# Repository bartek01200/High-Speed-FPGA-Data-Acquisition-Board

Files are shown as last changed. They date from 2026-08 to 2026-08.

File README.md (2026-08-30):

# ECP5 FPGA High Speed Data Acquisition System
A custom 4-layer mixed signal data acquisition PCB designed around a Lattice ECP5 FPGA and an analog devices AD9280 8 bit, 32 MSPS ADC.

The system combines analogue signal conditioning, multi rail power regulation, FPGA configuration circuitry and an 8-bit parallel ADC interface with a modular verilog acquisition pipeline for sample capture, FIFO buffering, acquisition control and streamed readout.

## Key Features:
- Lattice ECP5 LFE5U-12F-6BG256C FPGA
- Analog Devices AD9280 8 bit, 32 MSPS ADC
- Custom 4-layer mixed-signal PCB
- OPA836 analogue signal conditioning
- 1.1 V, 2.5 V and 3.3 V power rails
- 8-bit parallel ADC-to-FPGA interface
- FPGA configuration flash and JTAG programming interface
- Verilog ADC capture, FIFO buffering and acquisition control
- FSM-based buffered readout
- HDL simulation using Icarus Verilog and GTKWave
- FPGA synthesis using Yosys
- ECP5 place and route using nextpnr
- 32 MHz FPGA timing target successfully met

## Key metrics include:
The FPGA datapath handles a theoretical raw ADC input rate of 256 Mbit/s(32 MB/s), uses a 16-byte FIFO
,and met a 32MHz timing,using only 58 LUTs and 44 flip flop.

## Front PCB
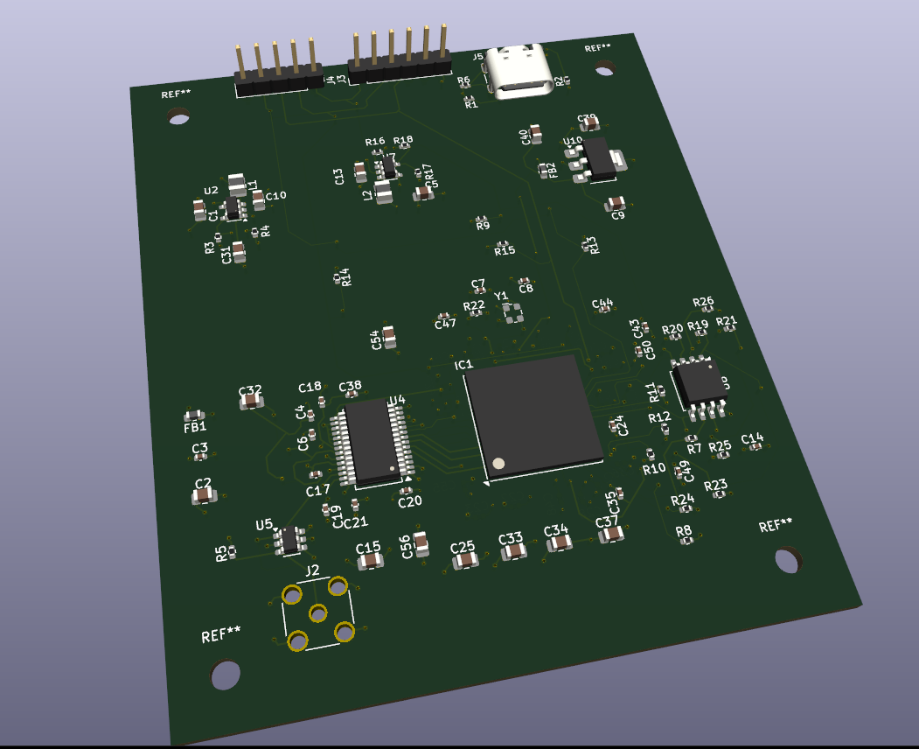
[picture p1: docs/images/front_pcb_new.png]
Front PCB


## Back PCB
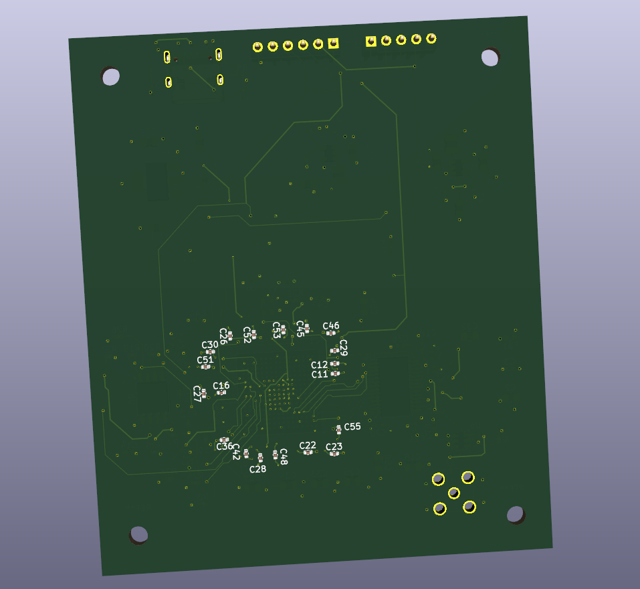
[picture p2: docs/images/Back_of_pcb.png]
Back PCB


## Hardware Build Disclaimer
This project was intended to be physically assembled and tested. However, Mouser cancelled the component order before shipment due to complience issues.I later found that all analog devices needed customer verification which i was not aware of, this included critical parts such as the AD9280 ADC and LT1963 2.5 V regulator.

As a result, the project was completed through PCB design, HDL simulation, synthesis and timing verification rather than physical hardware testing.

AI usage: Used AI for command line guidance and toolchain troubleshooting. All PCB design, HDL implementation, integration, simulation, and project documentation were completed by me.

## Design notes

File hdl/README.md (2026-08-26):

## FPGA HDL

This folder contains the Verilog implementation and simulation files for the FPGA data-acquisition path.
The design targets the Lattice ECP5`LFE5U-12F-6BG256C and implements an acquisition pipeline for the 8-bit parallel output of the AD9280 ADC.

## HDL Architecture
The FPGA datapath is divided into four main modules:

### adc_capture.v
Registers the incoming 8-bit ADC data on the sampling clock edge.
This provides a stable representation of each ADC sample inside the FPGA.

### `fifo.v`
Implements a synchronous FIFO used to buffer ADC samples.
The FIFO separates sample acquisition from readout so that acquired data can be stored before being transferred to the output interface.

It contains:
- sample memory
- write pointer
- read pointer
- occupancy counter
- full and empty status signals

### acquisition_ctrl.v
Controls when sampling begins and ends.

A start input begins an acquisition and the controller counts the required number of samples before disabling capture and asserting done.

### stream_tx.v
Reads samples from the FIFO and presents them through an 8-bit valid/ready streaming interface.
A three-state finite state machine is used:

IDLE → WAIT_FIFO → SEND

The WAIT_FIFO state accounts for the synchronous read latency of the FIFO before asserting tx_valid.

### daq_system.v
Top-level integration of the acquisition system.

The overall logic chain is:
ADC Data → Capture / Acquisition Control → FIFO → Stream Controller → Output

##Simulation
Icarus Verilog was used to simulate the HDL and GTKWave was used to inspect the resulting waveforms.

Individual modules were tested before integrating the complete system.
The final system test used the following sample sequence:
0x10 → 0x20 → 0x30 → 0x40 → 0x50 → 0x60 → 0x70 → 0x80

The same sequence was observed at the streamed output with no missing or reordered samples.

## Debugging and Design Changes

### FIFO Read Latency
The original streaming logic attempted to transmit FIFO data during the same cycle that a read was requested.
Because the FIFO uses synchronous reads, the requested value is not available until the following clock cycle.

The transmitter was therefore redesigned using:
IDLE → WAIT_FIFO → SEND
This ensures that the FIFO output is valid before transmission.

### ADC Pipeline Alignment
During integration, a one-clock offset was observed between the registered ADC sample and the FIFO write operation.

This occurred because non-blocking assignments update registers after the active clock event.

For the final simplified acquisition path, the FIFO write data was aligned directly with the ADC input bus while the registered sample remained available for monitoring and verification.

## 32 MHz Verification
The full acquisition datapath was simulated using a 31.25 ns clock period, corresponding to 32 MHz.
The complete sample sequence remained correct during the 32 MHz simulation.

The RTL was then:
- synthesized using Yosys
- placed and routed using nextpnr-ecp5
- timing analysed against a 32 MHz target
- packaged into an ECP5 bitstream using ecppack

The placed-and-routed design reported:
PASS at 32.00 MHz

with an internal maximum clock frequency of approximately:
233.54 MHz

The 233.54 MHz value represents the timing capability of the analysed internal FPGA paths and is not the sampling rate of the complete mixed-signal system.

## Physical Constraints
The PCB clock is connected to FPGA ball `E7`.
The AD9280 parallel data bus is mapped as follows:

 ADC ECP5 Ball 
- D0 - A2 
- D1 - B3 
- D2 - A3 
- D3 - A4 
- D4 - E4 
- D5 - D4 
- D6 - C4 
- D7 - B4 

Some simulation-oriented top-level interfaces were left physically unconstrained during timing analysis because the PCB was not assembled.

## Tools
- Verilog
- OSS CAD Suite
- Icarus Verilog
- GTKWave
- Yosys
- nextpnr-ecp5
- Project Trellis /ecppack

## Status
Completed:
- ADC capture logic
- FIFO buffering
- acquisition control
- streamed FIFO readout
- module level simulation
- full system simulation
- 32 MHz simulation
- ECP5 synthesis
- place and route
- 32 MHz timing verification
- bitstream generation

Not physically verified due to the board not being assembled.

### End to end simulation:
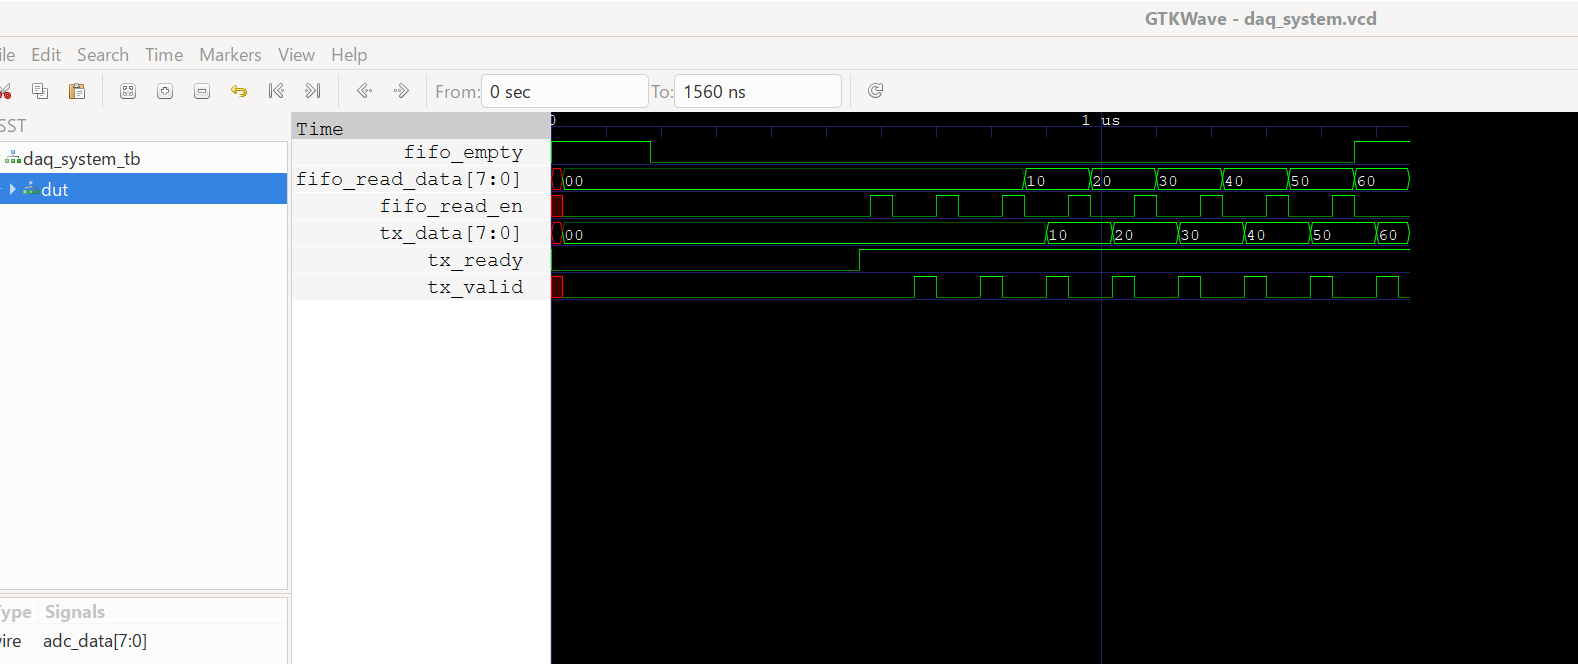
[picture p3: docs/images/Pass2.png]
DAQ system waveform


### FPGA timing verification:
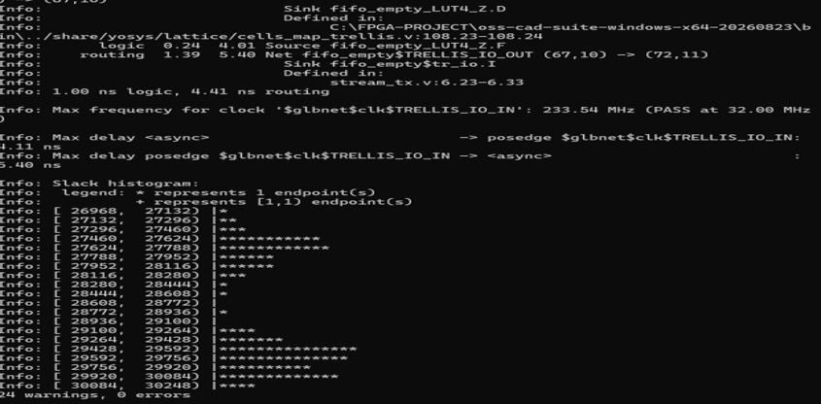
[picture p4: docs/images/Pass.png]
32MHz timing verification


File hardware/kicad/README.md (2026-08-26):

# Hardware Design

This folder contains the hardware design files for the high Speed FPGA Data Acquisition Board.

The board was designed around a Lattice ECP5 FPGA and Analog Devices AD9280 8-bit ADC, with analogue signal conditioning, multi rail power regulation, FPGA configuration circuitry and parallel ADC-to-FPGA routing implemented on a custom 4-layer PCB.

## Main components
- **FPGA:** Lattice  LFE5U-12F-6BG256C
- **ADC:** Analog Devices  AD9280ARSZRL — 8-bit ADC, rated up to 32 MSPS
- **Analogue Amplifier:** OPA836
- **Configuration Flash:** W25Q128JVS
- **System Oscillator:** 25 MHz ECS-2520MV oscillator
- **3.3 V Regulator:** TLV62569
- **1.1 V FPGA Core Regulator:** TLV62569
- **2.5 V Regulator:** LT1963
- **Programming Interface:** JTAG
- **Power Input:** USB-C

## PCB stack up
The board uses a 4-layer stack-up:
A 4-layer was chosen instead of a simpler 2-layer board because the design combines a BGA FPGA, parallel ADC data routing, multiple power rails and sensitive analogue circuitry.

 Layer - Purpose 
 F.Cu  - Components and primary signal routing 
 In1.Cu  -Continuous ground plane 
 In2.Cu  -Power distribution 
 B.Cu -Secondary signal routing 

Using a dedicated ground plane gives high speed signals a short return path, reduces loop area and makes the ADC to FPGA routing easier to read.

A separate internal power layer also makes it easier to distribute the 1.1V, 2.5V, 3.3V, 3.3VA and 5 V rails without filling the signal layers with wide power traces.

A 2-layer board would have made BGA escape routing, power distribution and maintaining good return paths a lot  more difficult.

## Power architecture
The board generates several supply rails from the USB-C 5 V input:

- 5 V — main input supply
- .3 V — FPGA I/O and digital circuitry
- 3.3 VA — filtered analogue supply
- 2.5 V — FPGA auxiliary supply
  - 1.1 V — FPGA core supply

Ferrite bead filtering is used to separate sensitive analogue supply sections from the main digital power network.
Local decoupling capacitors are positioned around the FPGA, ADC and supporting ICs to provide high-frequency current locally and reduce supply noise.

## ADC to FPGA Interface
The AD9280 presents each conversion to the FPGA through an 8-bit parallel digital bus.

 ADC Data - FPGA Ball 

- D0  - A2 
- D1  - B3 
- D2  - A3 
- D3  - A4 
- D4  - E4 
- D5  - D4 
- D6  - C4 
- D7  - B4 

This parallel interface allows the FPGA to capture the complete 8-bit ADC output on each sampling clock.

##Clocking
The board contains a **25 MHz oscillator** connected to FPGA ball E7.

`E7` is the physical BGA connection through which the clock signal enters the FPGA.

The clock provides the timing reference used by the FPGA logic and ADC acquisition system.

- The AD9280 itself is rated for operation up to 32 MSPS. The current PCB uses a 25 MHz onboard oscillator, so operation of the physical board at 32 MSPS would require an appropriate clock-source revision.

##FPGA Configuration

The hardware includes:
- JTAG programming interface
- External SPI configuration flash
- FPGA configuration support circuitry

The JTAG interface allows direct FPGA programming and debugging, while the external flash provides non volatile storage for FPGA configuration data.

## PCB Layout Considerations
The layout was designed with consideration for:
- Continuous signal return paths
- Short ADC-to-FPGA parallel routes
- Local decoupling
- Separation of analogue and digital power distribution
- FPGA BGA escape routing
- Dedicated internal ground plane
- Multi rail FPGA power requirements
- Short switching regulator current loops
  
##Design Status
The schematic and PCB layout have been completed and PCB design rule checks were performed.

The board has not been physically fabricated or electrically validated, therefore hardware performance measurements are outside the scope of the current project.

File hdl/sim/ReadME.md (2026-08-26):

#HDL simulation

The RTL was verified using Icarus Verliog and GTKWave

Verification order:
- adc_capture_tb.v - ADC input capture

- fifo_tb.v - FIFO write/read behaviour

- daq_core_tb.v - integrated ADC capture and buffering

- daq_system_tb.v = complete acquistion and streamed readout

  final system simulation used a 32Mhz clock verified:

  0x10 -> 0x20 -> 0x30 -> 0x40 -> 0x50 -> 0x60 -> 0x70 -> 0x80

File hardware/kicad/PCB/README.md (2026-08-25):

##PCB Design Rules
The PCB was routed as a 4-layer board with the following main design rules:

Parameter - Value 
- General signal trace width - 0.20 mm
- FPGA BGA escape trace width - 0.10 mm
- Standard via size - 0.60 mm 
- Standard via drill - 0.30 mm 
- BGA escape via size - 0.40 mm 
- BGA escape via drill - 0.20 mm 
- FPGA BGA pitch - 0.80 mm 
- Board thickness - 1.6 mm 
- Outer copper thickness - 35 µm

-checked with design rules checker-
## Priority zones

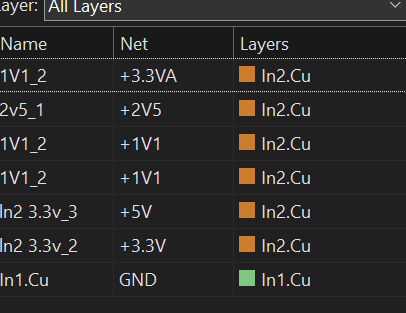
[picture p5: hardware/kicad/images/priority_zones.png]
Power Zone Priorities


Power-zone priority: +3.3VA → +2.5V → +1.1V → +5V → +3.3V. Higher priority zones retain their copper area where zones approach or overlap, helping preserve supply distribution.

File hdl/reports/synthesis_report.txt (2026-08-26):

 /----------------------------------------------------------------------------\
 |  yosys -- Yosys Open SYnthesis Suite                                       |
 |  Copyright (C) 2012 - 2026  Claire Xenia Wolf <claire@yosyshq.com>         |
 |  Distributed under an ISC-like license, type "license" to see terms        |
 \----------------------------------------------------------------------------/
 Yosys 0.68+120 (git sha1 a34d3baae-dirty, Release, GNU /usr/bin/x86_64-w64-mingw32-g++ 15.2.1)

-- Running command `read_verilog adc_capture.v fifo.v acquisition_ctrl.v stream_tx.v daq_system.v; synth_ecp5 -top daq_system -json build/daq_system.json' --

1. Executing Verilog-2005 frontend: adc_capture.v
Parsing Verilog input from `adc_capture.v' to AST representation.
Generating RTLIL representation for module `\adc_capture'.
Successfully finished Verilog frontend.

2. Executing Verilog-2005 frontend: fifo.v
Parsing Verilog input from `fifo.v' to AST representation.
Generating RTLIL representation for module `\fifo'.
Successfully finished Verilog frontend.

3. Executing Verilog-2005 frontend: acquisition_ctrl.v
Parsing Verilog input from `acquisition_ctrl.v' to AST representation.
Generating RTLIL representation for module `\acquisition_ctrl'.
Successfully finished Verilog frontend.

4. Executing Verilog-2005 frontend: stream_tx.v
Parsing Verilog input from `stream_tx.v' to AST representation.
Generating RTLIL representation for module `\stream_tx'.
Successfully finished Verilog frontend.

5. Executing Verilog-2005 frontend: daq_system.v
Parsing Verilog input from `daq_system.v' to AST representation.
Generating RTLIL representation for module `\daq_system'.
Successfully finished Verilog frontend.

6. Executing SYNTH_LATTICE pass.

6.1. Executing Verilog-2005 frontend: C:\FPGA-PROJECT\oss-cad-suite-windows-x64-20260823\bin\../share/yosys/lattice/cells_sim_ecp5.v
Parsing Verilog input from `C:\FPGA-PROJECT\oss-cad-suite-windows-x64-20260823\bin\../share/yosys/lattice/cells_sim_ecp5.v' to AST representation.
Generating RTLIL representation for module `\LUT4'.
Generating RTLIL representation for module `\$__ABC9_LUT5'.
Generating RTLIL representation for module `\$__ABC9_LUT6'.
Generating RTLIL representation for module `\$__ABC9_LUT7'.
Generating RTLIL representation for module `\L6MUX21'.
Generating RTLIL representation for module `\TRELLIS_RAM16X2'.
Generating RTLIL representation for module `\PFUMX'.
Generating RTLIL representation for module `\TRELLIS_DPR16X4'.
Generating RTLIL representation for module `\DPR16X4C'.
Generating RTLIL representation for module `\LUT2'.
Generating RTLIL representation for module `\TRELLIS_FF'.
Generating RTLIL representation for module `\TRELLIS_IO'.
Generating RTLIL representation for module `\INV'.
Generating RTLIL representation for module `\TRELLIS_COMB'.
Generating RTLIL representation for module `\VLO'.
Generating RTLIL representation for module `\VHI'.
Generating RTLIL representation for module `\FD1P3AX'.
Generating RTLIL representation for module `\FD1P3AY'.
Generating RTLIL representation for module `\FD1P3BX'.
Generating RTLIL representation for module `\FD1P3DX'.
Generating RTLIL representation for module `\FD1P3IX'.
Generating RTLIL representation for module `\FD1P3JX'.
Generating RTLIL representation for module `\FD1S3AX'.
Generating RTLIL representation for module `\FD1S3AY'.
Generating RTLIL representation for module `\FD1S3BX'.
Generating RTLIL representation for module `\FD1S3DX'.
Generating RTLIL representation for module `\FD1S3IX'.
Generating RTLIL representation for module `\FD1S3JX'.
Generating RTLIL representation for module `\IFS1P3BX'.
Generating RTLIL representation for module `\IFS1P3DX'.
Generating RTLIL representation for module `\IFS1P3IX'.
Generating RTLIL representation for module `\IFS1P3JX'.
Generating RTLIL representation for module `\OFS1P3BX'.
Generating RTLIL representation for module `\OFS1P3DX'.
Generating RTLIL representation for module `\OFS1P3IX'.
Generating RTLIL representation for module `\OFS1P3JX'.
Generating RTLIL representation for module `\IB'.
Generating RTLIL representation for module `\IBPU'.
Generating RTLIL representation for module `\IBPD'.
Generating RTLIL representation for module `\OB'.
Generating RTLIL representation for module `\OBZ'.
Generating RTLIL representation for module `\OBZPU'.
Generating RTLIL representation for module `\OBZPD'.
Generating RTLIL representation for module `\OBCO'.
Generating RTLIL representation for module `\BB'.
Generating RTLIL representation for module `\BBPU'.
Generating RTLIL representation for module `\BBPD'.
Generating RTLIL representation for module `\ILVDS'.
Generating RTLIL representation for module `\OLVDS'.
Generating RTLIL representation for module `\CCU2C'.
Generating RTLIL representation for module `\DP16KD'.
Replacing existing blackbox module `\FD1P3AX' at C:\FPGA-PROJECT\oss-cad-suite-windows-x64-20260823\bin\../share/yosys/lattice\cells_ff.vh:2.1-2.261.
Generating RTLIL representation for module `\FD1P3AX'.
Replacing existing blackbox module `\FD1P3AY' at C:\FPGA-PROJECT\oss-cad-suite-windows-x64-20260823\bin\../share/yosys/lattice\cells_ff.vh:3.1-3.261.
Generating RTLIL representation for module `\FD1P3AY'.
Replacing existing blackbox module `\FD1P3BX' at C:\FPGA-PROJECT\oss-cad-suite-windows-x64-20260823\bin\../share/yosys/lattice\cells_ff.vh:4.1-4.261.
Generating RTLIL representation for module `\FD1P3BX'.
Replacing existing blackbox module `\FD1P3DX' at C:\FPGA-PROJECT\oss-cad-suite-windows-x64-20260823\bin\../share/yosys/lattice\cells_ff.vh:5.1-5.261.
Generating RTLIL representation for module `\FD1P3DX'.
Replacing existing blackbox module `\FD1P3IX' at C:\FPGA-PROJECT\oss-cad-suite-windows-x64-20260823\bin\../share/yosys/lattice\cells_ff.vh:6.1-6.261.
Generating RTLIL representation for module `\FD1P3IX'.
Replacing existing blackbox module `\FD1P3JX' at C:\FPGA-PROJECT\oss-cad-suite-windows-x64-20260823\bin\../share/yosys/lattice\cells_ff.vh:7.1-7.261.
Generating RTLIL representation for module `\FD1P3JX'.
Replacing existing blackbox module `\FD1S3AX' at C:\FPGA-PROJECT\oss-cad-suite-windows-x64-20260823\bin\../share/yosys/lattice\cells_ff.vh:8.1-8.261.
Generating RTLIL representation for module `\FD1S3AX'.
Replacing existing blackbox module `\FD1S3AY' at C:\FPGA-PROJECT\oss-cad-suite-windows-x64-20260823\bin\../share/yosys/lattice\cells_ff.vh:9.1-9.261.
Generating RTLIL representation for module `\FD1S3AY'.
Replacing existing blackbox module `\FD1S3BX' at C:\FPGA-PROJECT\oss-cad-suite-windows-x64-20260823\bin\../share/yosys/lattice\cells_ff.vh:10.1-10.261.
Generating RTLIL representation for module `\FD1S3BX'.
Replacing existing blackbox module `\FD1S3DX' at C:\FPGA-PROJECT\oss-cad-suite-windows-x64-20260823\bin\../share/yosys/lattice\cells_ff.vh:11.1-11.261.
Generating RTLIL representation for module `\FD1S3DX'.
Replacing existing blackbox module `\FD1S3IX' at C:\FPGA-PROJECT\oss-cad-suite-windows-x64-20260823\bin\../share/yosys/lattice\cells_ff.vh:12.1-12.261.
Generating RTLIL representation for module `\FD1S3IX'.
Replacing existing blackbox module `\FD1S3JX' at C:\FPGA-PROJECT\oss-cad-suite-windows-x64-20260823\bin\../share/yosys/lattice\cells_ff.vh:13.1-13.261.
Generating RTLIL representation for module `\FD1S3JX'.
Replacing existing blackbox module `\IFS1P3BX' at C:\FPGA-PROJECT\oss-cad-suite-windows-x64-20260823\bin\../share/yosys/lattice\cells_ff.vh:26.1-26.301.
Generating RTLIL representation for module `\IFS1P3BX'.
Replacing existing blackbox module `\IFS1P3DX' at C:\FPGA-PROJECT\oss-cad-suite-windows-x64-20260823\bin\../share/yosys/lattice\cells_ff.vh:27.1-27.301.
Generating RTLIL representation for module `\IFS1P3DX'.
Replacing existing blackbox module `\IFS1P3IX' at C:\FPGA-PROJECT\oss-cad-suite-windows-x64-20260823\bin\../share/yosys/lattice\cells_ff.vh:28.1-28.301.
Generating RTLIL representation for module `\IFS1P3IX'.
Replacing existing blackbox module `\IFS1P3JX' at C:\FPGA-PROJECT\oss-cad-suite-windows-x64-20260823\bin\../share/yosys/lattice\cells_ff.vh:29.1-29.301.
Generating RTLIL representation for module `\IFS1P3JX'.
Replacing existing blackbox module `\OFS1P3BX' at C:\FPGA-PROJECT\oss-cad-suite-windows-x64-20260823\bin\../share/yosys/lattice\cells_ff.vh:31.1-31.302.
Generating RTLIL representation for module `\OFS1P3BX'.
Replacing existing blackbox module `\OFS1P3DX' at C:\FPGA-PROJECT\oss-cad-suite-windows-x64-20260823\bin\../share/yosys/lattice\cells_ff.vh:32.1-32.302.
Generating RTLIL representation for module `\OFS1P3DX'.
Replacing existing blackbox module `\OFS1P3IX' at C:\FPGA-PROJECT\oss-cad-suite-windows-x64-20260823\bin\../share/yosys/lattice\cells_ff.vh:33.1-33.302.
Generating RTLIL representation for module `\OFS1P3IX'.
Replacing existing blackbox module `\OFS1P3JX' at C:\FPGA-PROJECT\oss-cad-suite-windows-x64-20260823\bin\../share/yosys/lattice\cells_ff.vh:34.1-34.302.
Generating RTLIL representation for module `\OFS1P3JX'.
Replacing existing blackbox module `\IB' at C:\FPGA-PROJECT\oss-cad-suite-windows-x64-20260823\bin\../share/yosys/lattice\cells_io.vh:2.1-2.157.
Generating RTLIL representation for module `\IB'.
Replacing existing blackbox module `\IBPU' at C:\FPGA-PROJECT\oss-cad-suite-windows-x64-20260823\bin\../share/yosys/lattice\cells_io.vh:3.1-3.157.
Generating RTLIL representation for module `\IBPU'.
Replacing existing blackbox module `\IBPD' at C:\FPGA-PROJECT\oss-cad-suite-windows-x64-20260823\bin\../share/yosys/lattice\cells_io.vh:4.1-4.157.
Generating RTLIL representation for module `\IBPD'.
Replacing existing blackbox module `\OB' at C:\FPGA-PROJECT\oss-cad-suite-windows-x64-20260823\bin\../share/yosys/lattice\cells_io.vh:5.1-5.157.
Generating RTLIL representation for module `\OB'.
Replacing existing blackbox module `\OBZ' at C:\FPGA-PROJECT\oss-cad-suite-windows-x64-20260823\bin\../share/yosys/lattice\cells_io.vh:6.1-6.164.
Generating RTLIL representation for module `\OBZ'.
Replacing existing blackbox module `\OBZPU' at C:\FPGA-PROJECT\oss-cad-suite-windows-x64-20260823\bin\../share/yosys/lattice\cells_io.vh:7.1-7.164.
Generating RTLIL representation for module `\OBZPU'.
Replacing existing blackbox module `\OBZPD' at C:\FPGA-PROJECT\oss-cad-suite-windows-x64-20260823\bin\../share/yosys/lattice\cells_io.vh:8.1-8.164.
Generating RTLIL representation for module `\OBZPD'.
Replacing existing blackbox module `\OBCO' at C:\FPGA-PROJECT\oss-cad-suite-windows-x64-20260823\bin\../share/yosys/lattice\cells_io.vh:9.1-9.90.
Generating RTLIL representation for module `\OBCO'.
Replacing existing blackbox module `\BB' at C:\FPGA-PROJECT\oss-cad-suite-windows-x64-20260823\bin\../share/yosys/lattice\cells_io.vh:10.1-10.179.
Generating RTLIL representation for module `\BB'.
Replacing existing blackbox module `\BBPU' at C:\FPGA-PROJECT\oss-cad-suite-windows-x64-20260823\bin\../share/yosys/lattice\cells_io.vh:11.1-11.179.
Generating RTLIL representation for module `\BBPU'.
Replacing existing blackbox module `\BBPD' at C:\FPGA-PROJECT\oss-cad-suite-windows-x64-20260823\bin\../share/yosys/lattice\cells_io.vh:12.1-12.179.
Generating RTLIL representation for module `\BBPD'.
Replacing existing blackbox module `\ILVDS' at C:\FPGA-PROJECT\oss-cad-suite-windows-x64-20260823\bin\../share/yosys/lattice\cells_io.vh:13.1-13.139.
Generating RTLIL representation for module `\ILVDS'.
Replacing existing blackbox module `\OLVDS' at C:\FPGA-PROJECT\oss-cad-suite-windows-x64-20260823\bin\../share/yosys/lattice\cells_io.vh:14.1-14.146.
Generating RTLIL representation for module `\OLVDS'.
Successfully finished Verilog frontend.

6.2. Executing Verilog-2005 frontend: C:\FPGA-PROJECT\oss-cad-suite-windows-x64-20260823\bin\../share/yosys/lattice/cells_bb_ecp5.v
Parsing Verilog input from `C:\FPGA-PROJECT\oss-cad-suite-windows-x64-20260823\bin\../share/yosys/lattice/cells_bb_ecp5.v' to AST representation.
Generating RTLIL representation for module `\GSR'.
Generating RTLIL representation for module `\PUR'.
Generating RTLIL representation for module `\SGSR'.
Generating RTLIL representation for module `\PDPW16KD'.
Generating RTLIL representation for module `\MULT18X18D'.
Generating RTLIL representation for module `\ALU54B'.
Generating RTLIL representation for module `\CLKDIVF'.
Generating RTLIL representation for module `\PCSCLKDIV'.
Generating RTLIL representation for module `\DCSC'.
Generating RTLIL representation for module `\DCCA'.
Generating RTLIL representation for module `\ECLKSYNCB'.
Generating RTLIL representation for module `\ECLKBRIDGECS'.
Generating RTLIL representation for module `\DELAYF'.
Generating RTLIL representation for module `\DELAYG'.
Generating RTLIL representation for module `\USRMCLK'.
Generating RTLIL representation for module `\DQSBUFM'.
Generating RTLIL representation for module `\DDRDLLA'.
Generating RTLIL representation for module `\DLLDELD'.
Generating RTLIL representation for module `\IDDRX1F'.
Generating RTLIL representation for module `\IDDRX2F'.
Generating RTLIL representation for module `\IDDR71B'.
Generating RTLIL representation for module `\IDDRX2DQA'.
Generating RTLIL representation for module `\ODDRX1F'.
Generating RTLIL representation for module `\ODDRX2F'.
Generating RTLIL representation for module `\ODDR71B'.
Generating RTLIL representation for module `\OSHX2A'.
Generating RTLIL representation for module `\TSHX2DQA'.
Generating RTLIL representation for module `\TSHX2DQSA'.
Generating RTLIL representation for module `\ODDRX2DQA'.
Generating RTLIL representation for module `\ODDRX2DQSB'.
Generating RTLIL representation for module `\EHXPLLL'.
Generating RTLIL representation for module `\DTR'.
Generating RTLIL representation for module `\OSCG'.
Generating RTLIL representation for module `\EXTREFB'.
Generating RTLIL representation for module `\JTAGG'.
Generating RTLIL representation for module `\DCUA'.
Successfully finished Verilog frontend.

6.3. Executing HIERARCHY pass (managing design hierarchy).

6.3.1. Analyzing design hierarchy..
Top module:  \daq_system
Used module:     \stream_tx
Used module:     \fifo
Used module:     \acquisition_ctrl
Used module:     \adc_capture
Parameter \DATA_WIDTH = 8
Parameter \DEPTH = 16
Parameter \ADDR_WIDTH = 4

6.3.2. Executing AST frontend in derive mode using pre-parsed AST for module `\fifo'.
Parameter \DATA_WIDTH = 8
Parameter \DEPTH = 16
Parameter \ADDR_WIDTH = 4
Generating RTLIL representation for module `$paramod$6a1231bad6349c99ef10c6a6a58dbbf16b7d2bdb\fifo'.
Parameter \SAMPLE_COUNT = 8

6.3.3. Executing AST frontend in derive mode using pre-parsed AST for module `\acquisition_ctrl'.
Parameter \SAMPLE_COUNT = 8
Generating RTLIL representation for module `$paramod\acquisition_ctrl\SAMPLE_COUNT=s32'00000000000000000000000000001000'.

6.3.4. Analyzing design hierarchy..
Top module:  \daq_system
Used module:     \stream_tx
Used module:     $paramod$6a1231bad6349c99ef10c6a6a58dbbf16b7d2bdb\fifo
Used module:     $paramod\acquisition_ctrl\SAMPLE_COUNT=s32'00000000000000000000000000001000
Used module:     \adc_capture

6.3.5. Analyzing design hierarchy..
Top module:  \daq_system
Used module:     \stream_tx
Used module:     $paramod$6a1231bad6349c99ef10c6a6a58dbbf16b7d2bdb\fifo
Used module:     $paramod\acquisition_ctrl\SAMPLE_COUNT=s32'00000000000000000000000000001000
Used module:     \adc_capture
Removing unused module `\acquisition_ctrl'.
Removing unused module `\fifo'.
Removed 2 unused modules.

6.4. Executing PROC pass (convert processes to netlists).

6.4.1. Executing PROC_CLEAN pass (remove empty switches from decision trees).
Cleaned up 0 empty switches.

6.4.2. Executing PROC_RMDEAD pass (remove dead branches from decision trees).
Marked 2 switch rules as full_case in process $proc$stream_tx.v:20$38 in module stream_tx.
Marked 2 switch rules as full_case in process $proc$acquisition_ctrl.v:12$297 in module $paramod\acquisition_ctrl\SAMPLE_COUNT=s32'00000000000000000000000000001000.
Marked 3 switch rules as full_case in process $proc$fifo.v:27$271 in module $paramod$6a1231bad6349c99ef10c6a6a58dbbf16b7d2bdb\fifo.
Removed a total of 0 dead cases.

6.4.3. Executing PROC_PRUNE pass (remove redundant assignments in processes).
Removed 3 redundant assignments.
Promoted 8 assignments to connections.

6.4.4. Executing PROC_INIT pass (extract init attributes).
Found init rule in `$paramod$6a1231bad6349c99ef10c6a6a58dbbf16b7d2bdb\fifo.$proc$fifo.v:23$296'.
  Set init value: \count = 5'00000
Found init rule in `$paramod$6a1231bad6349c99ef10c6a6a58dbbf16b7d2bdb\fifo.$proc$fifo.v:21$295'.
  Set init value: \read_ptr = 4'0000
Found init rule in `$paramod$6a1231bad6349c99ef10c6a6a58dbbf16b7d2bdb\fifo.$proc$fifo.v:20$294'.
  Set init value: \write_ptr = 4'0000

6.4.5. Executing PROC_ARST pass (detect async resets in processes).

6.4.6. Executing PROC_ROM pass (convert switches to ROMs).
Converted 0 switches.
<suppressed ~11 debug messages>

6.4.7. Executing PROC_MUX pass (convert decision trees to multiplexers).
Creating decoders for process `\stream_tx.$proc$stream_tx.v:20$38'.
     1/4: $0\tx_valid[0:0]
     2/4: $0\fifo_read_en[0:0]
     3/4: $0\state[1:0]
     4/4: $0\tx_data[7:0]
Creating decoders for process `$paramod\acquisition_ctrl\SAMPLE_COUNT=s32'00000000000000000000000000001000.$proc$acquisition_ctrl.v:12$297'.
     1/3: $0\sample_counter[7:0]
     2/3: $0\done[0:0]
     3/3: $0\capture_en[0:0]
Creating decoders for process `$paramod$6a1231bad6349c99ef10c6a6a58dbbf16b7d2bdb\fifo.$proc$fifo.v:23$296'.
Creating decoders for process `$paramod$6a1231bad6349c99ef10c6a6a58dbbf16b7d2bdb\fifo.$proc$fifo.v:21$295'.
Creating decoders for process `$paramod$6a1231bad6349c99ef10c6a6a58dbbf16b7d2bdb\fifo.$proc$fifo.v:20$294'.
Creating decoders for process `$paramod$6a1231bad6349c99ef10c6a6a58dbbf16b7d2bdb\fifo.$proc$fifo.v:27$271'.
     1/10: $2$memwr$\memory$fifo.v:36$268_EN[7:0]$282
     2/10: $2$memwr$\memory$fifo.v:36$268_DATA[7:0]$281
     3/10: $2$memwr$\memory$fifo.v:36$268_ADDR[3:0]$280
     4/10: $0\count[4:0]
     5/10: $1$memwr$\memory$fifo.v:36$268_EN[7:0]$277
     6/10: $1$memwr$\memory$fifo.v:36$268_DATA[7:0]$276
     7/10: $1$memwr$\memory$fifo.v:36$268_ADDR[3:0]$275
     8/10: $0\read_ptr[3:0]
     9/10: $0\write_ptr[3:0]
    10/10: $0\read_data[7:0]
Creating decoders for process `\adc_capture.$proc$adc_capture.v:9$1'.

6.4.8. Executing PROC_DLATCH pass (convert process syncs to latches).

6.4.9. Executing PROC_DFF pass (convert process syncs to FFs).
Creating register for signal `\stream_tx.\fifo_read_en' using process `\stream_tx.$proc$stream_tx.v:20$38'.
  created $dff cell `$procdff$414' with positive edge clock.
Creating register for signal `\stream_tx.\tx_data' using process `\stream_tx.$proc$stream_tx.v:20$38'.
  created $dff cell `$procdff$415' with positive edge clock.
Creating register for signal `\stream_tx.\tx_valid' using process `\stream_tx.$proc$stream_tx.v:20$38'.
  created $dff cell `$procdff$416' with positive edge clock.
Creating register for signal `\stream_tx.\state' using process `\stream_tx.$proc$stream_tx.v:20$38'.
  created $dff cell `$procdff$417' with positive edge clock.
Creating register for signal `$paramod\acquisition_ctrl\SAMPLE_COUNT=s32'00000000000000000000000000001000.\capture_en' using process `$paramod\acquisition_ctrl\SAMPLE_COUNT=s32'00000000000000000000000000001000.$proc$acquisition_ctrl.v:12$297'.
  created $dff cell `$procdff$418' with positive edge clock.
Creating register for signal `$paramod\acquisition_ctrl\SAMPLE_COUNT=s32'00000000000000000000000000001000.\done' using process `$paramod\acquisition_ctrl\SAMPLE_COUNT=s32'00000000000000000000000000001000.$proc$acquisition_ctrl.v:12$297'.
  created $dff cell `$procdff$419' with positive edge clock.
Creating register for signal `$paramod\acquisition_ctrl\SAMPLE_COUNT=s32'00000000000000000000000000001000.\sample_counter' using process `$paramod\acquisition_ctrl\SAMPLE_COUNT=s32'00000000000000000000000000001000.$proc$acquisition_ctrl.v:12$297'.
  created $dff cell `$procdff$420' with positive edge clock.
Creating register for signal `$paramod$6a1231bad6349c99ef10c6a6a58dbbf16b7d2bdb\fifo.\read_data' using process `$paramod$6a1231bad6349c99ef10c6a6a58dbbf16b7d2bdb\fifo.$proc$fifo.v:27$271'.
  created $dff cell `$procdff$421' with positive edge clock.
Creating register for signal `$paramod$6a1231bad6349c99ef10c6a6a58dbbf16b7d2bdb\fifo.\write_ptr' using process `$paramod$6a1231bad6349c99ef10c6a6a58dbbf16b7d2bdb\fifo.$proc$fifo.v:27$271'.
  created $dff cell `$procdff$422' with positive edge clock.
Creating register for signal `$paramod$6a1231bad6349c99ef10c6a6a58dbbf16b7d2bdb\fifo.\read_ptr' using process `$paramod$6a1231bad6349c99ef10c6a6a58dbbf16b7d2bdb\fifo.$proc$fifo.v:27$271'.
  created $dff cell `$procdff$423' with positive edge clock.
Creating register for signal `$paramod$6a1231bad6349c99ef10c6a6a58dbbf16b7d2bdb\fifo.\count' using process `$paramod$6a1231bad6349c99ef10c6a6a58dbbf16b7d2bdb\fifo.$proc$fifo.v:27$271'.
  created $dff cell `$procdff$424' with positive edge clock.
Creating register for signal `$paramod$6a1231bad6349c99ef10c6a6a58dbbf16b7d2bdb\fifo.$memwr$\memory$fifo.v:36$268_ADDR' using process `$paramod$6a1231bad6349c99ef10c6a6a58dbbf16b7d2bdb\fifo.$proc$fifo.v:27$271'.
  created $dff cell `$procdff$425' with positive edge clock.
Creating register for signal `$paramod$6a1231bad6349c99ef10c6a6a58dbbf16b7d2bdb\fifo.$memwr$\memory$fifo.v:36$268_DATA' using process `$paramod$6a1231bad6349c99ef10c6a6a58dbbf16b7d2bdb\fifo.$proc$fifo.v:27$271'.
  created $dff cell `$procdff$426' with positive edge clock.
Creating register for signal `$paramod$6a1231bad6349c99ef10c6a6a58dbbf16b7d2bdb\fifo.$memwr$\memory$fifo.v:36$268_EN' using process `$paramod$6a1231bad6349c99ef10c6a6a58dbbf16b7d2bdb\fifo.$proc$fifo.v:27$271'.
  created $dff cell `$procdff$427' with positive edge clock.
Creating register for signal `\adc_capture.\sample' using process `\adc_capture.$proc$adc_capture.v:9$1'.
  created $dff cell `$procdff$428' with positive edge clock.
Creating register for signal `\adc_capture.\sample_valid' using process `\adc_capture.$proc$adc_capture.v:9$1'.
  created $dff cell `$procdff$429' with positive edge clock.

6.4.10. Executing PROC_MEMWR pass (convert process memory writes to cells).

6.4.11. Executing PROC_CLEAN pass (remove empty switches from decision trees).
Found and cleaned up 3 empty switches in `\stream_tx.$proc$stream_tx.v:20$38'.
Removing empty process `stream_tx.$proc$stream_tx.v:20$38'.
Found and cleaned up 4 empty switches in `$paramod\acquisition_ctrl\SAMPLE_COUNT=s32'00000000000000000000000000001000.$proc$acquisition_ctrl.v:12$297'.
Removing empty process `$paramod\acquisition_ctrl\SAMPLE_COUNT=s32'00000000000000000000000000001000.$proc$acquisition_ctrl.v:12$297'.
Removing empty process `$paramod$6a1231bad6349c99ef10c6a6a58dbbf16b7d2bdb\fifo.$proc$fifo.v:23$296'.
Removing empty process `$paramod$6a1231bad6349c99ef10c6a6a58dbbf16b7d2bdb\fifo.$proc$fifo.v:21$295'.
Removing empty process `$paramod$6a1231bad6349c99ef10c6a6a58dbbf16b7d2bdb\fifo.$proc$fifo.v:20$294'.
Found and cleaned up 4 empty switches in `$paramod$6a1231bad6349c99ef10c6a6a58dbbf16b7d2bdb\fifo.$proc$fifo.v:27$271'.
Removing empty process `$paramod$6a1231bad6349c99ef10c6a6a58dbbf16b7d2bdb\fifo.$proc$fifo.v:27$271'.
Removing empty process `adc_capture.$proc$adc_capture.v:9$1'.
Cleaned up 11 empty switches.

6.4.12. Executing OPT_EXPR pass (perform const folding).
Optimizing module daq_system.
Optimizing module stream_tx.
<suppressed ~2 debug messages>
Optimizing module $paramod\acquisition_ctrl\SAMPLE_COUNT=s32'00000000000000000000000000001000.
Optimizing module $paramod$6a1231bad6349c99ef10c6a6a58dbbf16b7d2bdb\fifo.
<suppressed ~1 debug messages>
Optimizing module adc_capture.

6.5. Executing CHECK pass (checking for obvious problems).
Checking module daq_system...
Checking module stream_tx...
Checking module $paramod\acquisition_ctrl\SAMPLE_COUNT=s32'00000000000000000000000000001000...
Checking module $paramod$6a1231bad6349c99ef10c6a6a58dbbf16b7d2bdb\fifo...
Checking module adc_capture...
Found and reported 0 problems.

6.6. Executing FLATTEN pass (flatten design).
Deleting now unused module stream_tx.
Deleting now unused module $paramod\acquisition_ctrl\SAMPLE_COUNT=s32'00000000000000000000000000001000.
Deleting now unused module $paramod$6a1231bad6349c99ef10c6a6a58dbbf16b7d2bdb\fifo.
Deleting now unused module adc_capture.
<suppressed ~4 debug messages>

6.7. Executing TRIBUF pass.

6.8. Executing DEMINOUT pass (demote inout ports to input or output).

6.9. Executing OPT_EXPR pass (perform const folding).
Optimizing module daq_system.

6.10. Executing OPT_CLEAN pass (remove unused cells and wires).
Finding unused cells or wires in module \daq_system..
Removed 5 unused cells and 68 unused wires.
<suppressed ~10 debug messages>

6.11. Executing CHECK pass (checking for obvious problems).
Checking module daq_system...
Found and reported 0 problems.

6.12. Executing OPT pass (performing simple optimizations).

6.12.1. Executing OPT_EXPR pass (perform const folding).
Optimizing module daq_system.

6.12.2. Executing OPT_MERGE pass (detect identical cells).
Finding identical cells in module `\daq_system'.
Computing hashes of 86 cells of `\daq_system'.
Finding duplicate cells in `\daq_system'.
Computing hashes of 80 cells of `\daq_system'.
Finding duplicate cells in `\daq_system'.
Computing hashes of 78 cells of `\daq_system'.
Finding duplicate cells in `\daq_system'.
<suppressed ~24 debug messages>
Removed a total of 8 cells.

6.12.3. Executing OPT_MUXTREE pass (detect dead branches in mux trees).
Running muxtree optimizer on module \daq_system..
  Creating internal representation of mux trees.
  Evaluating internal representation of mux trees.
  Analyzing evaluation results.
    dead port 1/2 on $mux $flatten\fifo_inst.$procmux$368.
    dead port 1/2 on $mux $flatten\fifo_inst.$procmux$374.
    dead port 1/2 on $mux $flatten\fifo_inst.$procmux$380.
Removed 3 multiplexer ports.
<suppressed ~58 debug messages>

6.12.4. Executing OPT_REDUCE pass (consolidate $*mux and $reduce_* inputs).
  Optimizing cells in module \daq_system.
    Consolidated identical input bits for $mux cell $flatten\fifo_inst.$procmux$365:
      Old ports: A=8'00000000, B=8'11111111, Y=$flatten\fifo_inst.$procmux$365_Y
      New ports: A=1'0, B=1'1, Y=$flatten\fifo_inst.$procmux$365_Y [0]
      New connections: $flatten\fifo_inst.$procmux$365_Y [7:1] = { $flatten\fifo_inst.$procmux$365_Y [0] $flatten\fifo_inst.$procmux$365_Y [0] $flatten\fifo_inst.$procmux$365_Y [0] $flatten\fifo_inst.$procmux$365_Y [0] $flatten\fifo_inst.$procmux$365_Y [0] $flatten\fifo_inst.$procmux$365_Y [0] $flatten\fifo_inst.$procmux$365_Y [0] }
  Optimizing cells in module \daq_system.
    Consolidated identical input bits for $mux cell $flatten\fifo_inst.$procmux$390:
      Old ports: A=$flatten\fifo_inst.$2$memwr$\memory$fifo.v:36$268_EN[7:0]$282, B=8'00000000, Y=$flatten\fifo_inst.$0$memwr$\memory$fifo.v:36$268_EN[7:0]$274
      New ports: A=$flatten\fifo_inst.$procmux$365_Y [0], B=1'0, Y=$flatten\fifo_inst.$0$memwr$\memory$fifo.v:36$268_EN[7:0]$274 [0]
      New connections: $flatten\fifo_inst.$0$memwr$\memory$fifo.v:36$268_EN[7:0]$274 [7:1] = { $flatten\fifo_inst.$0$memwr$\memory$fifo.v:36$268_EN[7:0]$274 [0] $flatten\fifo_inst.$0$memwr$\memory$fifo.v:36$268_EN[7:0]$274 [0] $flatten\fifo_inst.$0$memwr$\memory$fifo.v:36$268_EN[7:0]$274 [0] $flatten\fifo_inst.$0$memwr$\memory$fifo.v:36$268_EN[7:0]$274 [0] $flatten\fifo_inst.$0$memwr$\memory$fifo.v:36$268_EN[7:0]$274 [0] $flatten\fifo_inst.$0$memwr$\memory$fifo.v:36$268_EN[7:0]$274 [0] $flatten\fifo_inst.$0$memwr$\memory$fifo.v:36$268_EN[7:0]$274 [0] }
  Optimizing cells in module \daq_system.
Performed a total of 2 changes.

6.12.5. Executing OPT_MERGE pass (detect identical cells).
Finding identical cells in module `\daq_system'.
Computing hashes of 75 cells of `\daq_system'.
Finding duplicate cells in `\daq_system'.
Removed a total of 0 cells.

6.12.6. Executing OPT_DFF pass (perform DFF optimizations).

6.12.7. Executing OPT_CLEAN pass (remove unused cells and wires).
Finding unused cells or wires in module \daq_system..
Removed 0 unused cells and 11 unused wires.
<suppressed ~1 debug messages>

6.12.8. Executing OPT_EXPR pass (perform const folding).
Optimizing module daq_system.

6.12.9. Rerunning OPT passes. (Maybe there is more to do..)

6.12.10. Executing OPT_MUXTREE pass (detect dead branches in mux trees).
Running muxtree optimizer on module \daq_system..
  Creating internal representation of mux trees.
  Evaluating internal representation of mux trees.
  Analyzing evaluation results.
Removed 0 multiplexer ports.
<suppressed ~55 debug messages>

6.12.11. Executing OPT_REDUCE pass (consolidate $*mux and $reduce_* inputs).
  Optimizing cells in module \daq_system.
Performed a total of 0 changes.

6.12.12. Executing OPT_MERGE pass (detect identical cells).
Finding identical cells in module `\daq_system'.
Computing hashes of 75 cells of `\daq_system'.
Finding duplicate cells in `\daq_system'.
Removed a total of 0 cells.

6.12.13. Executing OPT_DFF pass (perform DFF optimizations).

6.12.14. Executing OPT_CLEAN pass (remove unused cells and wires).
Finding unused cells or wires in module \daq_system..

6.12.15. Executing OPT_EXPR pass (perform const folding).
Optimizing module daq_system.

6.12.16. Finished fast OPT passes. (There is nothing left to do.)

6.13. Executing FSM pass (extract and optimize FSM).

6.13.1. Executing FSM_DETECT pass (finding FSMs in design).
Found FSM state register daq_system.stream_inst.state.

6.13.2. Executing FSM_EXTRACT pass (extracting FSM from design).
Extracting FSM `\stream_inst.state' from module `\daq_system'.
  found $dff cell for state register: $flatten\stream_inst.$procdff$417
  root of input selection tree: $flatten\stream_inst.$0\state[1:0]
  found reset state: 2'00 (guessed from mux tree)
  found ctrl input: \reset
  found ctrl input: $flatten\stream_inst.$procmux$323_CMP
  found ctrl input: $flatten\stream_inst.$procmux$316_CMP
  found state code: 2'00
  found state code: 2'10
  found ctrl input: $flatten\stream_inst.$logic_and$stream_tx.v:34$40_Y
  found state code: 2'01
  found ctrl output: $flatten\stream_inst.$procmux$306_CMP
  found ctrl output: $flatten\stream_inst.$procmux$323_CMP
  found ctrl output: $flatten\stream_inst.$procmux$316_CMP
  ctrl inputs: { $flatten\stream_inst.$logic_and$stream_tx.v:34$40_Y \reset }
  ctrl outputs: { $flatten\stream_inst.$0\state[1:0] $flatten\stream_inst.$procmux$306_CMP $flatten\stream_inst.$procmux$316_CMP $flatten\stream_inst.$procmux$323_CMP }
  transition:       2'00 2'00 ->       2'00 5'00010
  transition:       2'00 2'10 ->       2'01 5'01010
  transition:       2'00 2'-1 ->       2'00 5'00010
  transition:       2'10 2'-0 ->       2'00 5'00100
  transition:       2'10 2'-1 ->       2'00 5'00100
  transition:       2'01 2'-0 ->       2'10 5'10001
  transition:       2'01 2'-1 ->       2'00 5'00001

6.13.3. Executing FSM_OPT pass (simple optimizations of FSMs).
Optimizing FSM `$fsm$\stream_inst.state$435' from module `\daq_system'.
  Merging pattern 2'-0 and 2'-1 from group (1 0 5'00100).
  Merging pattern 2'-1 and 2'-0 from group (1 0 5'00100).

6.13.4. Executing OPT_CLEAN pass (remove unused cells and wires).
Finding unused cells or wires in module \daq_system..
Removed 7 unused cells and 7 unused wires.
<suppressed ~8 debug messages>

6.13.5. Executing FSM_OPT pass (simple optimizations of FSMs).
Optimizing FSM `$fsm$\stream_inst.state$435' from module `\daq_system'.
  Removing unused output signal $flatten\stream_inst.$procmux$323_CMP.
  Removing unused output signal $flatten\stream_inst.$0\state[1:0] [0].
  Removing unused output signal $flatten\stream_inst.$0\state[1:0] [1].

6.13.6. Executing FSM_RECODE pass (re-assigning FSM state encoding).
Recoding FSM `$fsm$\stream_inst.state$435' from module `\daq_system' using `auto' encoding:
  mapping auto encoding to `one-hot` for this FSM.
  00 -> --1
  10 -> -1-
  01 -> 1--

6.13.7. Executing FSM_INFO pass (dumping all available information on FSM cells).

FSM `$fsm$\stream_inst.state$435' from module `daq_system':
-------------------------------------

  Information on FSM $fsm$\stream_inst.state$435 (\stream_inst.state):

  Number of input signals:    2
  Number of output signals:   2
  Number of state bits:       3

  Input signals:
    0: \reset
    1: $flatten\stream_inst.$logic_and$stream_tx.v:34$40_Y

  Output signals:
    0: $flatten\stream_inst.$procmux$316_CMP
    1: $flatten\stream_inst.$procmux$306_CMP

  State encoding:
    0:      3'--1  <RESET STATE>
    1:      3'-1-
    2:      3'1--

  Transition Table (state_in, ctrl_in, state_out, ctrl_out):
      0:     0 2'00   ->     0 2'01
      1:     0 2'-1   ->     0 2'01
      2:     0 2'10   ->     2 2'01
      3:     1 2'--   ->     0 2'10
      4:     2 2'-1   ->     0 2'00
      5:     2 2'-0   ->     1 2'00

-------------------------------------

6.13.8. Executing FSM_MAP pass (mapping FSMs to basic logic).
Mapping FSM `$fsm$\stream_inst.state$435' from module `\daq_system'.

6.14. Executing OPT pass (performing simple optimizations).

6.14.1. Executing OPT_EXPR pass (perform const folding).
Optimizing module daq_system.
<suppressed ~3 debug messages>

6.14.2. Executing OPT_MERGE pass (detect identical cells).
Finding identical cells in module `\daq_system'.
Computing hashes of 76 cells of `\daq_system'.
Finding duplicate cells in `\daq_system'.
Removed a total of 0 cells.

6.14.3. Executing OPT_MUXTREE pass (detect dead branches in mux trees).
Running muxtree optimizer on module \daq_system..
  Creating internal representation of mux trees.
  Evaluating internal representation of mux trees.
  Analyzing evaluation results.
Removed 0 multiplexer ports.
<suppressed ~51 debug messages>

6.14.4. Executing OPT_REDUCE pass (consolidate $*mux and $reduce_* inputs).
  Optimizing cells in module \daq_system.
Performed a total of 0 changes.

6.14.5. Executing OPT_MERGE pass (detect identical cells).
Finding identical cells in module `\daq_system'.
Computing hashes of 76 cells of `\daq_system'.
Finding duplicate cells in `\daq_system'.
Removed a total of 0 cells.

6.14.6. Executing OPT_DFF pass (perform DFF optimizations).
Adding SRST signal on $flatten\stream_inst.$procdff$416 ($dff) from module daq_system (D = $flatten\stream_inst.$procmux$305_Y, Q = \stream_inst.tx_valid, rval = 1'0).
Adding SRST signal on $flatten\control_inst.$procdff$420 ($dff) from module daq_system (D = $flatten\control_inst.$procmux$341_Y, Q = \control_inst.sample_counter, rval = 8'00000000).
Adding SRST signal on $flatten\control_inst.$procdff$419 ($dff) from module daq_system (D = $flatten\control_inst.$procmux$349_Y, Q = \control_inst.done, rval = 1'0).
Adding EN signal on $auto$ff.cc:337:slice$461 ($sdff) from module daq_system (D = 1'1, Q = \control_inst.done).
Adding SRST signal on $flatten\control_inst.$procdff$418 ($dff) from module daq_system (D = $flatten\control_inst.$procmux$359_Y, Q = \control_inst.capture_en, rval = 1'0).
Adding SRST signal on $flatten\fifo_inst.$procdff$424 ($dff) from module daq_system (D = $flatten\fifo_inst.$procmux$383_Y, Q = \fifo_inst.count, rval = 5'00000).
Adding EN signal on $auto$ff.cc:337:slice$466 ($sdff) from module daq_system (D = $flatten\fifo_inst.$procmux$383_Y, Q = \fifo_inst.count).
Adding SRST signal on $flatten\fifo_inst.$procdff$423 ($dff) from module daq_system (D = $flatten\fifo_inst.$procmux$398_Y, Q = \fifo_inst.read_ptr, rval = 4'0000).
Adding EN signal on $auto$ff.cc:337:slice$470 ($sdff) from module daq_system (D = $flatten\fifo_inst.$add$fifo.v:42$287_Y, Q = \fifo_inst.read_ptr).
Adding SRST signal on $flatten\fifo_inst.$procdff$422 ($dff) from module daq_system (D = $flatten\fifo_inst.$procmux$404_Y, Q = \fifo_inst.write_ptr, rval = 4'0000).
Adding EN signal on $auto$ff.cc:337:slice$472 ($sdff) from module daq_system (D = $flatten\fifo_inst.$add$fifo.v:37$283_Y, Q = \fifo_inst.write_ptr).
Adding SRST signal on $flatten\fifo_inst.$procdff$421 ($dff) from module daq_system (D = $flatten\fifo_inst.$procmux$409_Y, Q = \fifo_inst.read_data, rval = 8'00000000).
Adding EN signal on $auto$ff.cc:337:slice$474 ($sdff) from module daq_system (D = $flatten\fifo_inst.$memrd$\memory$fifo.v:41$286_DATA, Q = \fifo_inst.read_data).
Adding SRST signal on $flatten\stream_inst.$procdff$414 ($dff) from module daq_system (D = $flatten\stream_inst.$procmux$313_Y, Q = \stream_inst.fifo_read_en, rval = 1'0).
Adding SRST signal on $flatten\stream_inst.$procdff$415 ($dff) from module daq_system (D = $flatten\stream_inst.$procmux$331_Y, Q = \stream_inst.tx_data, rval = 8'00000000).
Adding EN signal on $auto$ff.cc:337:slice$481 ($sdff) from module daq_system (D = \fifo_inst.read_data, Q = \stream_inst.tx_data).

6.14.7. Executing OPT_CLEAN pass (remove unused cells and wires).
Finding unused cells or wires in module \daq_system..
Removed 17 unused cells and 24 unused wires.
<suppressed ~18 debug messages>

6.14.8. Executing OPT_EXPR pass (perform const folding).
Optimizing module daq_system.
<suppressed ~1 debug messages>

6.14.9. Rerunning OPT passes. (Maybe there is more to do..)

6.14.10. Executing OPT_MUXTREE pass (detect dead branches in mux trees).
Running muxtree optimizer on module \daq_system..
  Creating internal representation of mux trees.
  Evaluating internal representation of mux trees.
  Analyzing evaluation results.
Removed 0 multiplexer ports.
<suppressed ~29 debug messages>

6.14.11. Executing OPT_REDUCE pass (consolidate $*mux and $reduce_* inputs).
  Optimizing cells in module \daq_system.
Performed a total of 0 changes.

6.14.12. Executing OPT_MERGE pass (detect identical cells).
Finding identical cells in module `\daq_system'.
Computing hashes of 63 cells of `\daq_system'.
Finding duplicate cells in `\daq_system'.
Removed a total of 0 cells.

6.14.13. Executing OPT_DFF pass (perform DFF optimizations).

6.14.14. Executing OPT_CLEAN pass (remove unused cells and wires).
Finding unused cells or wires in module \daq_system..

6.14.15. Executing OPT_EXPR pass (perform const folding).
Optimizing module daq_system.

6.14.16. Finished fast OPT passes. (There is nothing left to do.)

6.15. Executing WREDUCE pass (reducing word size of cells).
Removed top 5 bits (of 8) from port B of cell daq_system.$flatten\control_inst.$eq$acquisition_ctrl.v:24$302 ($eq).
Removed top 1 bits (of 2) from port B of cell daq_system.$flatten\fifo_inst.$procmux$384_CMP0 ($eq).

6.16. Executing PEEPOPT pass (run peephole optimizers).

6.17. Executing OPT_CLEAN pass (remove unused cells and wires).
Finding unused cells or wires in module \daq_system..

6.18. Executing SHARE pass (SAT-based resource sharing).

6.19. Executing TECHMAP pass (map to technology primitives).

6.19.1. Executing Verilog-2005 frontend: C:\FPGA-PROJECT\oss-cad-suite-windows-x64-20260823\bin\../share/yosys/cmp2lut.v
Parsing Verilog input from `C:\FPGA-PROJECT\oss-cad-suite-windows-x64-20260823\bin\../share/yosys/cmp2lut.v' to AST representation.
Generating RTLIL representation for module `\_90_lut_cmp_'.
Successfully finished Verilog frontend.

6.19.2. Continuing TECHMAP pass.
No more expansions possible.
<suppressed ~6 debug messages>

6.20. Executing OPT_EXPR pass (perform const folding).
Optimizing module daq_system.

6.21. Executing OPT_CLEAN pass (remove unused cells and wires).
Finding unused cells or wires in module \daq_system..

6.22. Executing TECHMAP pass (map to technology primitives).

6.22.1. Executing Verilog-2005 frontend: C:\FPGA-PROJECT\oss-cad-suite-windows-x64-20260823\bin\../share/yosys/mul2dsp.v
Parsing Verilog input from `C:\FPGA-PROJECT\oss-cad-suite-windows-x64-20260823\bin\../share/yosys/mul2dsp.v' to AST representation.
Generating RTLIL representation for module `\_80_mul'.
Generating RTLIL representation for module `\_90_soft_mul'.
Successfully finished Verilog frontend.

6.22.2. Continuing TECHMAP pass.
No more expansions possible.
<suppressed ~4 debug messages>

6.23. Executing TECHMAP pass (map to technology primitives).

6.23.1. Executing Verilog-2005 frontend: C:\FPGA-PROJECT\oss-cad-suite-windows-x64-20260823\bin\../share/yosys/lattice/dsp_map_18x18.v
Parsing Verilog input from `C:\FPGA-PROJECT\oss-cad-suite-windows-x64-20260823\bin\../share/yosys/lattice/dsp_map_18x18.v' to AST representation.
Generating RTLIL representation for module `$__MUL18X18'.
Successfully finished Verilog frontend.

6.23.2. Continuing TECHMAP pass.
No more expansions possible.
<suppressed ~3 debug messages>

6.24. Executing ALUMACC pass (create $alu and $macc cells).
Extracting $alu and $macc cells in module daq_system:
  creating $macc model for $flatten\fifo_inst.$add$fifo.v:42$287 ($add).
  creating $macc model for $flatten\fifo_inst.$add$fifo.v:50$292 ($add).
  creating $macc model for $flatten\fifo_inst.$sub$fifo.v:51$293 ($sub).
  creating $macc model for $flatten\fifo_inst.$add$fifo.v:37$283 ($add).
  creating $macc model for $flatten\control_inst.$add$acquisition_ctrl.v:29$303 ($add).
  creating $alu model for $macc $flatten\control_inst.$add$acquisition_ctrl.v:29$303.
  creating $alu model for $macc $flatten\fifo_inst.$add$fifo.v:37$283.
  creating $alu model for $macc $flatten\fifo_inst.$sub$fifo.v:51$293.
  creating $alu model for $macc $flatten\fifo_inst.$add$fifo.v:50$292.
  creating $alu model for $macc $flatten\fifo_inst.$add$fifo.v:42$287.
  creating $alu cell for $flatten\fifo_inst.$add$fifo.v:42$287: $auto$alumacc.cc:548:replace_alu$484
  creating $alu cell for $flatten\fifo_inst.$add$fifo.v:50$292: $auto$alumacc.cc:548:replace_alu$487
  creating $alu cell for $flatten\fifo_inst.$sub$fifo.v:51$293: $auto$alumacc.cc:548:replace_alu$490
  creating $alu cell for $flatten\fifo_inst.$add$fifo.v:37$283: $auto$alumacc.cc:548:replace_alu$493
  creating $alu cell for $flatten\control_inst.$add$acquisition_ctrl.v:29$303: $auto$alumacc.cc:548:replace_alu$496
  created 5 $alu and 0 $macc cells.

6.25. Executing OPT pass (performing simple optimizations).

6.25.1. Executing OPT_EXPR pass (perform const folding).
Optimizing module daq_system.

6.25.2. Executing OPT_MERGE pass (detect identical cells).
Finding identical cells in module `\daq_system'.
Computing hashes of 63 cells of `\daq_system'.
Finding duplicate cells in `\daq_system'.
Removed a total of 0 cells.

6.25.3. Executing OPT_MUXTREE pass (detect dead branches in mux trees).
Running muxtree optimizer on module \daq_system..
  Creating internal representation of mux trees.
  Evaluating internal representation of mux trees.
  Analyzing evaluation results.
Removed 0 multiplexer ports.
<suppressed ~29 debug messages>

6.25.4. Executing OPT_REDUCE pass (consolidate $*mux and $reduce_* inputs).
  Optimizing cells in module \daq_system.
Performed a total of 0 changes.

6.25.5. Executing OPT_MERGE pass (detect identical cells).
Finding identical cells in module `\daq_system'.
Computing hashes of 63 cells of `\daq_system'.
Finding duplicate cells in `\daq_system'.
Removed a total of 0 cells.

6.25.6. Executing OPT_DFF pass (perform DFF optimizations).

6.25.7. Executing OPT_CLEAN pass (remove unused cells and wires).
Finding unused cells or wires in module \daq_system..

6.25.8. Executing OPT_EXPR pass (perform const folding).
Optimizing module daq_system.

6.25.9. Finished fast OPT passes. (There is nothing left to do.)

6.26. Executing MEMORY pass.

6.26.1. Executing OPT_MEM pass (optimize memories).
Performed a total of 0 transformations.

6.26.2. Executing OPT_MEM_PRIORITY pass (removing unnecessary memory write priority relations).
Performed a total of 0 transformations.

6.26.3. Executing OPT_MEM_FEEDBACK pass (finding memory read-to-write feedback paths).
  Analyzing daq_system.fifo_inst.memory write port 0.

6.26.4. Executing MEMORY_BMUX2ROM pass (converting muxes to ROMs).

6.26.5. Executing MEMORY_DFF pass (merging $dff cells to $memrd).
Checking read port `\fifo_inst.memory'[0] in module `\daq_system': merging output FF to cell.
    Write port 0: non-transparent.

6.26.6. Executing OPT_CLEAN pass (remove unused cells and wires).
Finding unused cells or wires in module \daq_system..
Removed 1 unused cells and 9 unused wires.
<suppressed ~2 debug messages>

6.26.7. Executing MEMORY_SHARE pass (consolidating $memrd/$memwr cells).

6.26.8. Executing OPT_MEM_WIDEN pass (optimize memories where all ports are wide).
Performed a total of 0 transformations.

6.26.9. Executing OPT_CLEAN pass (remove unused cells and wires).
Finding unused cells or wires in module \daq_system..

6.26.10. Executing MEMORY_COLLECT pass (generating $mem cells).

6.27. Executing OPT_CLEAN pass (remove unused cells and wires).
Finding unused cells or wires in module \daq_system..

6.28. Executing MEMORY_LIBMAP pass (mapping memories to cells).
mapping memory daq_system.fifo_inst.memory via $__TRELLIS_DPR16X4_
Extracted data FF from read port 0 of daq_system.fifo_inst.memory: $\fifo_inst.memory$rdreg[0]
<suppressed ~491 debug messages>

6.29. Executing TECHMAP pass (map to technology primitives).

6.29.1. Executing Verilog-2005 frontend: C:\FPGA-PROJECT\oss-cad-suite-windows-x64-20260823\bin\../share/yosys/lattice/lutrams_map_trellis.v
Parsing Verilog input from `C:\FPGA-PROJECT\oss-cad-suite-windows-x64-20260823\bin\../share/yosys/lattice/lutrams_map_trellis.v' to AST representation.
Generating RTLIL representation for module `$__TRELLIS_DPR16X4_'.
Successfully finished Verilog frontend.

6.29.2. Executing Verilog-2005 frontend: C:\FPGA-PROJECT\oss-cad-suite-windows-x64-20260823\bin\../share/yosys/lattice/brams_map_16kd.v
Parsing Verilog input from `C:\FPGA-PROJECT\oss-cad-suite-windows-x64-20260823\bin\../share/yosys/lattice/brams_map_16kd.v' to AST representation.
Generating RTLIL representation for module `$__DP16KD_'.
Generating RTLIL representation for module `$__PDPW16KD_'.
Successfully finished Verilog frontend.

6.29.3. Continuing TECHMAP pass.
Using template $paramod$04778961cc1285a5efea28f98f28381eb2862208$__TRELLIS_DPR16X4_ for cells of type $__TRELLIS_DPR16X4_.
No more expansions possible.
<suppressed ~20 debug messages>

6.30. Executing OPT pass (performing simple optimizations).

6.30.1. Executing OPT_EXPR pass (perform const folding).
Optimizing module daq_system.
<suppressed ~8 debug messages>

6.30.2. Executing OPT_MERGE pass (detect identical cells).
Finding identical cells in module `\daq_system'.
Computing hashes of 56 cells of `\daq_system'.
Finding duplicate cells in `\daq_system'.
Removed a total of 0 cells.

6.30.3. Executing OPT_DFF pass (perform DFF optimizations).

6.30.4. Executing OPT_CLEAN pass (remove unused cells and wires).
Finding unused cells or wires in module \daq_system..
Removed 0 unused cells and 21 unused wires.
<suppressed ~1 debug messages>

6.30.5. Finished fast OPT passes.

6.31. Executing MEMORY_MAP pass (converting memories to logic and flip-flops).

6.32. Executing OPT pass (performing simple optimizations).

6.32.1. Executing OPT_EXPR pass (perform const folding).
Optimizing module daq_system.

6.32.2. Executing OPT_MERGE pass (detect identical cells).
Finding identical cells in module `\daq_system'.
Computing hashes of 56 cells of `\daq_system'.
Finding duplicate cells in `\daq_system'.
Removed a total of 0 cells.

6.32.3. Executing OPT_MUXTREE pass (detect dead branches in mux trees).
Running muxtree optimizer on module \daq_system..
  Creating internal representation of mux trees.
  Evaluating internal representation of mux trees.
  Analyzing evaluation results.
Removed 0 multiplexer ports.
<suppressed ~18 debug messages>

6.32.4. Executing OPT_REDUCE pass (consolidate $*mux and $reduce_* inputs).
  Optimizing cells in module \daq_system.
Performed a total of 0 changes.

6.32.5. Executing OPT_MERGE pass (detect identical cells).
Finding identical cells in module `\daq_system'.
Computing hashes of 56 cells of `\daq_system'.
Finding duplicate cells in `\daq_system'.
Removed a total of 0 cells.

6.32.6. Executing OPT_DFF pass (perform DFF optimizations).

6.32.7. Executing OPT_CLEAN pass (remove unused cells and wires).
Finding unused cells or wires in module \daq_system..

6.32.8. Executing OPT_EXPR pass (perform const folding).
Optimizing module daq_system.

6.32.9. Finished fast OPT passes. (There is nothing left to do.)

6.33. Executing TECHMAP pass (map to technology primitives).

6.33.1. Executing Verilog-2005 frontend: C:\FPGA-PROJECT\oss-cad-suite-windows-x64-20260823\bin\../share/yosys/techmap.v
Parsing Verilog input from `C:\FPGA-PROJECT\oss-cad-suite-windows-x64-20260823\bin\../share/yosys/techmap.v' to AST representation.
Generating RTLIL representation for module `\_90_simplemap_bool_ops'.
Generating RTLIL representation for module `\_90_simplemap_reduce_ops'.
Generating RTLIL representation for module `\_90_simplemap_logic_ops'.
Generating RTLIL representation for module `\_90_simplemap_compare_ops'.
Generating RTLIL representation for module `\_90_simplemap_various'.
Generating RTLIL representation for module `\_90_simplemap_registers'.
Generating RTLIL representation for module `\_90_shift_ops_shr_shl_sshl_sshr'.
Generating RTLIL representation for module `\_90_shift_shiftx'.
Generating RTLIL representation for module `\_90_fa'.
Generating RTLIL representation for module `\_90_lcu_brent_kung'.
Generating RTLIL representation for module `\_90_alu'.
Generating RTLIL representation for module `\_90_macc'.
Generating RTLIL representation for module `\_90_alumacc'.
Generating RTLIL representation for module `$__div_mod_u'.
Generating RTLIL representation for module `$__div_mod_trunc'.
Generating RTLIL representation for module `\_90_div'.
Generating RTLIL representation for module `\_90_mod'.
Generating RTLIL representation for module `$__div_mod_floor'.
Generating RTLIL representation for module `\_90_divfloor'.
Generating RTLIL representation for module `\_90_modfloor'.
Generating RTLIL representation for module `\_90_pow'.
Generating RTLIL representation for module `\_90_demux'.
Generating RTLIL representation for module `\_90_lut'.
Generating RTLIL representation for module `$connect'.
Generating RTLIL representation for module `$input_port'.
Successfully finished Verilog frontend.

6.33.2. Executing Verilog-2005 frontend: C:\FPGA-PROJECT\oss-cad-suite-windows-x64-20260823\bin\../share/yosys/lattice/arith_map_ccu2c.v
Parsing Verilog input from `C:\FPGA-PROJECT\oss-cad-suite-windows-x64-20260823\bin\../share/yosys/lattice/arith_map_ccu2c.v' to AST representation.
Generating RTLIL representation for module `\_80_ccu2c_alu'.
Successfully finished Verilog frontend.

6.33.3. Continuing TECHMAP pass.
Using template $paramod$c3cd1564c35d873179656addd6052d7ea8b6d991\_80_ccu2c_alu for cells of type $alu.
Using template $paramod$32a7b7b86c07519b7537abc18e96f0331f97914d\_90_alu for cells of type $alu.
Using template $paramod$dc04b7d98e503a7bab16fce2df70e6e2c5ca34d6\_80_ccu2c_alu for cells of type $alu.
Using template $paramod$672a140277c71df8314410f22acc08d55222c3c7\_80_ccu2c_alu for cells of type $alu.
Using extmapper simplemap for cells of type $sdffe.
Using extmapper simplemap for cells of type $reduce_or.
Using extmapper simplemap for cells of type $not.
Using extmapper simplemap for cells of type $sdff.
Using extmapper simplemap for cells of type $reduce_bool.
Using extmapper simplemap for cells of type $reduce_and.
Using extmapper simplemap for cells of type $and.
Using extmapper simplemap for cells of type $eq.
Using extmapper simplemap for cells of type $logic_not.
Using extmapper simplemap for cells of type $dff.
Using extmapper simplemap for cells of type $logic_and.
Using extmapper simplemap for cells of type $mux.
Using extmapper simplemap for cells of type $logic_or.
Using extmapper simplemap for cells of type $xor.
Using extmapper simplemap for cells of type $pos.
Using template $paramod\_90_fa\WIDTH=32'00000000000000000000000000000100 for cells of type $fa.
Using template $paramod\_90_lcu_brent_kung\WIDTH=32'00000000000000000000000000000100 for cells of type $lcu.
Using extmapper simplemap for cells of type $or.
No more expansions possible.
<suppressed ~446 debug messages>

6.34. Executing OPT pass (performing simple optimizations).

6.34.1. Executing OPT_EXPR pass (perform const folding).
Optimizing module daq_system.
<suppressed ~181 debug messages>

6.34.2. Executing OPT_MERGE pass (detect identical cells).
Finding identical cells in module `\daq_system'.
Computing hashes of 194 cells of `\daq_system'.
Finding duplicate cells in `\daq_system'.
Computing hashes of 180 cells of `\daq_system'.
Finding duplicate cells in `\daq_system'.
Computing hashes of 179 cells of `\daq_system'.
Finding duplicate cells in `\daq_system'.
<suppressed ~45 debug messages>
Removed a total of 15 cells.

6.34.3. Executing OPT_DFF pass (perform DFF optimizations).

6.34.4. Executing OPT_CLEAN pass (remove unused cells and wires).
Finding unused cells or wires in module \daq_system..
Removed 26 unused cells and 217 unused wires.
<suppressed ~27 debug messages>

6.34.5. Finished fast OPT passes.

6.35. Executing OPT_CLEAN pass (remove unused cells and wires).
Finding unused cells or wires in module \daq_system..

6.36. Executing DFFLEGALIZE pass (convert FFs and LATCHes to types supported by the target).

6.37. Executing OPT_MERGE pass (detect identical cells).
Finding identical cells in module `\daq_system'.
Computing hashes of 153 cells of `\daq_system'.
Finding duplicate cells in `\daq_system'.
Removed a total of 0 cells.

6.38. Executing TECHMAP pass (map to technology primitives).

6.38.1. Executing Verilog-2005 frontend: C:\FPGA-PROJECT\oss-cad-suite-windows-x64-20260823\bin\../share/yosys/lattice/cells_map_trellis.v
Parsing Verilog input from `C:\FPGA-PROJECT\oss-cad-suite-windows-x64-20260823\bin\../share/yosys/lattice/cells_map_trellis.v' to AST representation.
Generating RTLIL representation for module `$_DFF_N_'.
Generating RTLIL representation for module `$_DFF_P_'.
Generating RTLIL representation for module `$_DFFE_NN_'.
Generating RTLIL representation for module `$_DFFE_PN_'.
Generating RTLIL representation for module `$_DFFE_NP_'.
Generating RTLIL representation for module `$_DFFE_PP_'.
Generating RTLIL representation for module `$_DFF_NP0_'.
Generating RTLIL representation for module `$_DFF_NP1_'.
Generating RTLIL representation for module `$_DFF_PP0_'.
Generating RTLIL representation for module `$_DFF_PP1_'.
Generating RTLIL representation for module `$_SDFF_NP0_'.
Generating RTLIL representation for module `$_SDFF_NP1_'.
Generating RTLIL representation for module `$_SDFF_PP0_'.
Generating RTLIL representation for module `$_SDFF_PP1_'.
Generating RTLIL representation for module `$_DFFE_NP0P_'.
Generating RTLIL representation for module `$_DFFE_NP1P_'.
Generating RTLIL representation for module `$_DFFE_PP0P_'.
Generating RTLIL representation for module `$_DFFE_PP1P_'.
Generating RTLIL representation for module `$_DFFE_NP0N_'.
Generating RTLIL representation for module `$_DFFE_NP1N_'.
Generating RTLIL representation for module `$_DFFE_PP0N_'.
Generating RTLIL representation for module `$_DFFE_PP1N_'.
Generating RTLIL representation for module `$_SDFFE_NP0P_'.
Generating RTLIL representation for module `$_SDFFE_NP1P_'.
Generating RTLIL representation for module `$_SDFFE_PP0P_'.
Generating RTLIL representation for module `$_SDFFE_PP1P_'.
Generating RTLIL representation for module `$_SDFFE_NP0N_'.
Generating RTLIL representation for module `$_SDFFE_NP1N_'.
Generating RTLIL representation for module `$_SDFFE_PP0N_'.
Generating RTLIL representation for module `$_SDFFE_PP1N_'.
Generating RTLIL representation for module `$_ALDFF_NP_'.
Generating RTLIL representation for module `$_ALDFF_PP_'.
Generating RTLIL representation for module `$_ALDFFE_NPN_'.
Generating RTLIL representation for module `$_ALDFFE_NPP_'.
Generating RTLIL representation for module `$_ALDFFE_PPN_'.
Generating RTLIL representation for module `$_ALDFFE_PPP_'.
Generating RTLIL representation for module `\FD1P3AX'.
Generating RTLIL representation for module `\FD1P3AY'.
Generating RTLIL representation for module `\FD1P3BX'.
Generating RTLIL representation for module `\FD1P3DX'.
Generating RTLIL representation for module `\FD1P3IX'.
Generating RTLIL representation for module `\FD1P3JX'.
Generating RTLIL representation for module `\FD1S3AX'.
Generating RTLIL representation for module `\FD1S3AY'.
Generating RTLIL representation for module `\FD1S3BX'.
Generating RTLIL representation for module `\FD1S3DX'.
Generating RTLIL representation for module `\FD1S3IX'.
Generating RTLIL representation for module `\FD1S3JX'.
Generating RTLIL representation for module `\IFS1P3BX'.
Generating RTLIL representation for module `\IFS1P3DX'.
Generating RTLIL representation for module `\IFS1P3IX'.
Generating RTLIL representation for module `\IFS1P3JX'.
Generating RTLIL representation for module `\OFS1P3BX'.
Generating RTLIL representation for module `\OFS1P3DX'.
Generating RTLIL representation for module `\OFS1P3IX'.
Generating RTLIL representation for module `\OFS1P3JX'.
Generating RTLIL representation for module `\IB'.
Generating RTLIL representation for module `\IBPU'.
Generating RTLIL representation for module `\IBPD'.
Generating RTLIL representation for module `\OB'.
Generating RTLIL representation for module `\OBZ'.
Generating RTLIL representation for module `\OBZPU'.
Generating RTLIL representation for module `\OBZPD'.
Generating RTLIL representation for module `\OBCO'.
Generating RTLIL representation for module `\BB'.
Generating RTLIL representation for module `\BBPU'.
Generating RTLIL representation for module `\BBPD'.
Generating RTLIL representation for module `\ILVDS'.
Generating RTLIL representation for module `\OLVDS'.
Successfully finished Verilog frontend.

6.38.2. Continuing TECHMAP pass.
Using template $_SDFFE_PP0P_ for cells of type $_SDFFE_PP0P_.
Using template $paramod$_DFF_P_\_TECHMAP_WIREINIT_Q_=1'x for cells of type $_DFF_P_.
Using template $_SDFF_PP0_ for cells of type $_SDFF_PP0_.
No more expansions possible.
<suppressed ~126 debug messages>

6.39. Executing OPT_EXPR pass (perform const folding).
Optimizing module daq_system.

6.40. Executing SIMPLEMAP pass (map simple cells to gate primitives).

6.41. Executing LATTICE_GSR pass (implement FF init values).
Handling GSR in daq_system.

6.42. Executing ATTRMVCP pass (move or copy attributes).

6.43. Executing OPT_CLEAN pass (remove unused cells and wires).
Finding unused cells or wires in module \daq_system..
Removed 0 unused cells and 247 unused wires.
<suppressed ~1 debug messages>

6.44. Executing CHECK pass (checking for obvious problems).
Checking module daq_system...
Found and reported 0 problems.

6.45. Executing TECHMAP pass (map to technology primitives).

6.45.1. Executing Verilog-2005 frontend: C:\FPGA-PROJECT\oss-cad-suite-windows-x64-20260823\bin\../share/yosys/lattice/latches_map.v
Parsing Verilog input from `C:\FPGA-PROJECT\oss-cad-suite-windows-x64-20260823\bin\../share/yosys/lattice/latches_map.v' to AST representation.
Generating RTLIL representation for module `$_DLATCH_N_'.
Generating RTLIL representation for module `$_DLATCH_P_'.
Successfully finished Verilog frontend.

6.45.2. Continuing TECHMAP pass.
No more expansions possible.
<suppressed ~4 debug messages>

6.46. Executing ABC9 pass.

6.46.1. Executing ABC9_OPS pass (helper functions for ABC9).

6.46.2. Executing ABC9_OPS pass (helper functions for ABC9).

6.46.3. Executing PROC pass (convert processes to netlists).

6.46.3.1. Executing PROC_CLEAN pass (remove empty switches from decision trees).
Found and cleaned up 1 empty switch in `$paramod$2074b3813575c9ede27f9a04ee0bf291c9c7bf2f\TRELLIS_DPR16X4.$proc$C:\FPGA-PROJECT\oss-cad-suite-windows-x64-20260823\bin\../share/yosys/lattice\common_sim.vh:151$1318'.
Cleaned up 1 empty switch.

6.46.3.2. Executing PROC_RMDEAD pass (remove dead branches from decision trees).
Marked 1 switch rules as full_case in process $proc$C:\FPGA-PROJECT\oss-cad-suite-windows-x64-20260823\bin\../share/yosys/lattice\common_sim.vh:159$1319 in module $paramod$2074b3813575c9ede27f9a04ee0bf291c9c7bf2f\TRELLIS_DPR16X4.
Removed a total of 0 dead cases.

6.46.3.3. Executing PROC_PRUNE pass (remove redundant assignments in processes).
Removed 0 redundant assignments.
Promoted 22 assignments to connections.

6.46.3.4. Executing PROC_INIT pass (extract init attributes).

6.46.3.5. Executing PROC_ARST pass (detect async resets in processes).

6.46.3.6. Executing PROC_ROM pass (convert switches to ROMs).
Converted 0 switches.
<suppressed ~1 debug messages>

6.46.3.7. Executing PROC_MUX pass (convert decision trees to multiplexers).
Creating decoders for process `$paramod$2074b3813575c9ede27f9a04ee0bf291c9c7bf2f\TRELLIS_DPR16X4.$proc$C:\FPGA-PROJECT\oss-cad-suite-windows-x64-20260823\bin\../share/yosys/lattice\common_sim.vh:143$1343'.
Creating decoders for process `$paramod$2074b3813575c9ede27f9a04ee0bf291c9c7bf2f\TRELLIS_DPR16X4.$proc$C:\FPGA-PROJECT\oss-cad-suite-windows-x64-20260823\bin\../share/yosys/lattice\common_sim.vh:159$1319'.
     1/3: $1$memwr$\mem$C:\FPGA-PROJECT\oss-cad-suite-windows-x64-20260823\bin\../share/yosys/lattice\common_sim.vh:161$1317_EN[3:0]$1325
     2/3: $1$memwr$\mem$C:\FPGA-PROJECT\oss-cad-suite-windows-x64-20260823\bin\../share/yosys/lattice\common_sim.vh:161$1317_DATA[3:0]$1324
     3/3: $1$memwr$\mem$C:\FPGA-PROJECT\oss-cad-suite-windows-x64-20260823\bin\../share/yosys/lattice\common_sim.vh:161$1317_ADDR[3:0]$1323
Creating decoders for process `$paramod$2074b3813575c9ede27f9a04ee0bf291c9c7bf2f\TRELLIS_DPR16X4.$proc$C:\FPGA-PROJECT\oss-cad-suite-windows-x64-20260823\bin\../share/yosys/lattice\common_sim.vh:151$1318'.

6.46.3.8. Executing PROC_DLATCH pass (convert process syncs to latches).
No latch inferred for signal `$paramod$2074b3813575c9ede27f9a04ee0bf291c9c7bf2f\TRELLIS_DPR16X4.\i' from process `$paramod$2074b3813575c9ede27f9a04ee0bf291c9c7bf2f\TRELLIS_DPR16X4.$proc$C:\FPGA-PROJECT\oss-cad-suite-windows-x64-20260823\bin\../share/yosys/lattice\common_sim.vh:143$1343'.
No latch inferred for signal `$paramod$2074b3813575c9ede27f9a04ee0bf291c9c7bf2f\TRELLIS_DPR16X4.$memwr$\mem$C:\FPGA-PROJECT\oss-cad-suite-windows-x64-20260823\bin\../share/yosys/lattice\common_sim.vh:145$1301_EN' from process `$paramod$2074b3813575c9ede27f9a04ee0bf291c9c7bf2f\TRELLIS_DPR16X4.$proc$C:\FPGA-PROJECT\oss-cad-suite-windows-x64-20260823\bin\../share/yosys/lattice\common_sim.vh:143$1343'.
No latch inferred for signal `$paramod$2074b3813575c9ede27f9a04ee0bf291c9c7bf2f\TRELLIS_DPR16X4.$memwr$\mem$C:\FPGA-PROJECT\oss-cad-suite-windows-x64-20260823\bin\../share/yosys/lattice\common_sim.vh:145$1302_EN' from process `$paramod$2074b3813575c9ede27f9a04ee0bf291c9c7bf2f\TRELLIS_DPR16X4.$proc$C:\FPGA-PROJECT\oss-cad-suite-windows-x64-20260823\bin\../share/yosys/lattice\common_sim.vh:143$1343'.
No latch inferred for signal `$paramod$2074b3813575c9ede27f9a04ee0bf291c9c7bf2f\TRELLIS_DPR16X4.$memwr$\mem$C:\FPGA-PROJECT\oss-cad-suite-windows-x64-20260823\bin\../share/yosys/lattice\common_sim.vh:145$1303_EN' from process `$paramod$2074b3813575c9ede27f9a04ee0bf291c9c7bf2f\TRELLIS_DPR16X4.$proc$C:\FPGA-PROJECT\oss-cad-suite-windows-x64-20260823\bin\../share/yosys/lattice\common_sim.vh:143$1343'.
No latch inferred for signal `$paramod$2074b3813575c9ede27f9a04ee0bf291c9c7bf2f\TRELLIS_DPR16X4.$memwr$\mem$C:\FPGA-PROJECT\oss-cad-suite-windows-x64-20260823\bin\../share/yosys/lattice\common_sim.vh:145$1304_EN' from process `$paramod$2074b3813575c9ede27f9a04ee0bf291c9c7bf2f\TRELLIS_DPR16X4.$proc$C:\FPGA-PROJECT\oss-cad-suite-windows-x64-20260823\bin\../share/yosys/lattice\common_sim.vh:143$1343'.
No latch inferred for signal `$paramod$2074b3813575c9ede27f9a04ee0bf291c9c7bf2f\TRELLIS_DPR16X4.$memwr$\mem$C:\FPGA-PROJECT\oss-cad-suite-windows-x64-20260823\bin\../share/yosys/lattice\common_sim.vh:145$1305_EN' from process `$paramod$2074b3813575c9ede27f9a04ee0bf291c9c7bf2f\TRELLIS_DPR16X4.$proc$C:\FPGA-PROJECT\oss-cad-suite-windows-x64-20260823\bin\../share/yosys/lattice\common_sim.vh:143$1343'.
No latch inferred for signal `$paramod$2074b3813575c9ede27f9a04ee0bf291c9c7bf2f\TRELLIS_DPR16X4.$memwr$\mem$C:\FPGA-PROJECT\oss-cad-suite-windows-x64-20260823\bin\../share/yosys/lattice\common_sim.vh:145$1306_EN' from process `$paramod$2074b3813575c9ede27f9a04ee0bf291c9c7bf2f\TRELLIS_DPR16X4.$proc$C:\FPGA-PROJECT\oss-cad-suite-windows-x64-20260823\bin\../share/yosys/lattice\common_sim.vh:143$1343'.
No latch inferred for signal `$paramod$2074b3813575c9ede27f9a04ee0bf291c9c7bf2f\TRELLIS_DPR16X4.$memwr$\mem$C:\FPGA-PROJECT\oss-cad-suite-windows-x64-20260823\bin\../share/yosys/lattice\common_sim.vh:145$1307_EN' from process `$paramod$2074b3813575c9ede27f9a04ee0bf291c9c7bf2f\TRELLIS_DPR16X4.$proc$C:\FPGA-PROJECT\oss-cad-suite-windows-x64-20260823\bin\../share/yosys/lattice\common_sim.vh:143$1343'.
No latch inferred for signal `$paramod$2074b3813575c9ede27f9a04ee0bf291c9c7bf2f\TRELLIS_DPR16X4.$memwr$\mem$C:\FPGA-PROJECT\oss-cad-suite-windows-x64-20260823\bin\../share/yosys/lattice\common_sim.vh:145$1308_EN' from process `$paramod$2074b3813575c9ede27f9a04ee0bf291c9c7bf2f\TRELLIS_DPR16X4.$proc$C:\FPGA-PROJECT\oss-cad-suite-windows-x64-20260823\bin\../share/yosys/lattice\common_sim.vh:143$1343'.
No latch inferred for signal `$paramod$2074b3813575c9ede27f9a04ee0bf291c9c7bf2f\TRELLIS_DPR16X4.$memwr$\mem$C:\FPGA-PROJECT\oss-cad-suite-windows-x64-20260823\bin\../share/yosys/lattice\common_sim.vh:145$1309_EN' from process `$paramod$2074b3813575c9ede27f9a04ee0bf291c9c7bf2f\TRELLIS_DPR16X4.$proc$C:\FPGA-PROJECT\oss-cad-suite-windows-x64-20260823\bin\../share/yosys/lattice\common_sim.vh:143$1343'.
No latch inferred for signal `$paramod$2074b3813575c9ede27f9a04ee0bf291c9c7bf2f\TRELLIS_DPR16X4.$memwr$\mem$C:\FPGA-PROJECT\oss-cad-suite-windows-x64-20260823\bin\../share/yosys/lattice\common_sim.vh:145$1310_EN' from process `$paramod$2074b3813575c9ede27f9a04ee0bf291c9c7bf2f\TRELLIS_DPR16X4.$proc$C:\FPGA-PROJECT\oss-cad-suite-windows-x64-20260823\bin\../share/yosys/lattice\common_sim.vh:143$1343'.
No latch inferred for signal `$paramod$2074b3813575c9ede27f9a04ee0bf291c9c7bf2f\TRELLIS_DPR16X4.$memwr$\mem$C:\FPGA-PROJECT\oss-cad-suite-windows-x64-20260823\bin\../share/yosys/lattice\common_sim.vh:145$1311_EN' from process `$paramod$2074b3813575c9ede27f9a04ee0bf291c9c7bf2f\TRELLIS_DPR16X4.$proc$C:\FPGA-PROJECT\oss-cad-suite-windows-x64-20260823\bin\../share/yosys/lattice\common_sim.vh:143$1343'.
No latch inferred for signal `$paramod$2074b3813575c9ede27f9a04ee0bf291c9c7bf2f\TRELLIS_DPR16X4.$memwr$\mem$C:\FPGA-PROJECT\oss-cad-suite-windows-x64-20260823\bin\../share/yosys/lattice\common_sim.vh:145$1312_EN' from process `$paramod$2074b3813575c9ede27f9a04ee0bf291c9c7bf2f\TRELLIS_DPR16X4.$proc$C:\FPGA-PROJECT\oss-cad-suite-windows-x64-20260823\bin\../share/yosys/lattice\common_sim.vh:143$1343'.
No latch inferred for signal `$paramod$2074b3813575c9ede27f9a04ee0bf291c9c7bf2f\TRELLIS_DPR16X4.$memwr$\mem$C:\FPGA-PROJECT\oss-cad-suite-windows-x64-20260823\bin\../share/yosys/lattice\common_sim.vh:145$1313_EN' from process `$paramod$2074b3813575c9ede27f9a04ee0bf291c9c7bf2f\TRELLIS_DPR16X4.$proc$C:\FPGA-PROJECT\oss-cad-suite-windows-x64-20260823\bin\../share/yosys/lattice\common_sim.vh:143$1343'.
No latch inferred for signal `$paramod$2074b3813575c9ede27f9a04ee0bf291c9c7bf2f\TRELLIS_DPR16X4.$memwr$\mem$C:\FPGA-PROJECT\oss-cad-suite-windows-x64-20260823\bin\../share/yosys/lattice\common_sim.vh:145$1314_EN' from process `$paramod$2074b3813575c9ede27f9a04ee0bf291c9c7bf2f\TRELLIS_DPR16X4.$proc$C:\FPGA-PROJECT\oss-cad-suite-windows-x64-20260823\bin\../share/yosys/lattice\common_sim.vh:143$1343'.
No latch inferred for signal `$paramod$2074b3813575c9ede27f9a04ee0bf291c9c7bf2f\TRELLIS_DPR16X4.$memwr$\mem$C:\FPGA-PROJECT\oss-cad-suite-windows-x64-20260823\bin\../share/yosys/lattice\common_sim.vh:145$1315_EN' from process `$paramod$2074b3813575c9ede27f9a04ee0bf291c9c7bf2f\TRELLIS_DPR16X4.$proc$C:\FPGA-PROJECT\oss-cad-suite-windows-x64-20260823\bin\../share/yosys/lattice\common_sim.vh:143$1343'.
No latch inferred for signal `$paramod$2074b3813575c9ede27f9a04ee0bf291c9c7bf2f\TRELLIS_DPR16X4.$memwr$\mem$C:\FPGA-PROJECT\oss-cad-suite-windows-x64-20260823\bin\../share/yosys/lattice\common_sim.vh:145$1316_EN' from process `$paramod$2074b3813575c9ede27f9a04ee0bf291c9c7bf2f\TRELLIS_DPR16X4.$proc$C:\FPGA-PROJECT\oss-cad-suite-windows-x64-20260823\bin\../share/yosys/lattice\common_sim.vh:143$1343'.
No latch inferred for signal `$paramod$2074b3813575c9ede27f9a04ee0bf291c9c7bf2f\TRELLIS_DPR16X4.\muxwre' from process `$paramod$2074b3813575c9ede27f9a04ee0bf291c9c7bf2f\TRELLIS_DPR16X4.$proc$C:\FPGA-PROJECT\oss-cad-suite-windows-x64-20260823\bin\../share/yosys/lattice\common_sim.vh:151$1318'.

6.46.3.9. Executing PROC_DFF pass (convert process syncs to FFs).
Creating register for signal `$paramod$2074b3813575c9ede27f9a04ee0bf291c9c7bf2f\TRELLIS_DPR16X4.$memwr$\mem$C:\FPGA-PROJECT\oss-cad-suite-windows-x64-20260823\bin\../share/yosys/lattice\common_sim.vh:161$1317_ADDR' using process `$paramod$2074b3813575c9ede27f9a04ee0bf291c9c7bf2f\TRELLIS_DPR16X4.$proc$C:\FPGA-PROJECT\oss-cad-suite-windows-x64-20260823\bin\../share/yosys/lattice\common_sim.vh:159$1319'.
  created $dff cell `$procdff$1369' with positive edge clock.
Creating register for signal `$paramod$2074b3813575c9ede27f9a04ee0bf291c9c7bf2f\TRELLIS_DPR16X4.$memwr$\mem$C:\FPGA-PROJECT\oss-cad-suite-windows-x64-20260823\bin\../share/yosys/lattice\common_sim.vh:161$1317_DATA' using process `$paramod$2074b3813575c9ede27f9a04ee0bf291c9c7bf2f\TRELLIS_DPR16X4.$proc$C:\FPGA-PROJECT\oss-cad-suite-windows-x64-20260823\bin\../share/yosys/lattice\common_sim.vh:159$1319'.
  created $dff cell `$procdff$1370' with positive edge clock.
Creating register for signal `$paramod$2074b3813575c9ede27f9a04ee0bf291c9c7bf2f\TRELLIS_DPR16X4.$memwr$\mem$C:\FPGA-PROJECT\oss-cad-suite-windows-x64-20260823\bin\../share/yosys/lattice\common_sim.vh:161$1317_EN' using process `$paramod$2074b3813575c9ede27f9a04ee0bf291c9c7bf2f\TRELLIS_DPR16X4.$proc$C:\FPGA-PROJECT\oss-cad-suite-windows-x64-20260823\bin\../share/yosys/lattice\common_sim.vh:159$1319'.
  created $dff cell `$procdff$1371' with positive edge clock.

6.46.3.10. Executing PROC_MEMWR pass (convert process memory writes to cells).

6.46.3.11. Executing PROC_CLEAN pass (remove empty switches from decision trees).
Removing empty process `$paramod$2074b3813575c9ede27f9a04ee0bf291c9c7bf2f\TRELLIS_DPR16X4.$proc$C:\FPGA-PROJECT\oss-cad-suite-windows-x64-20260823\bin\../share/yosys/lattice\common_sim.vh:143$1343'.
Found and cleaned up 1 empty switch in `$paramod$2074b3813575c9ede27f9a04ee0bf291c9c7bf2f\TRELLIS_DPR16X4.$proc$C:\FPGA-PROJECT\oss-cad-suite-windows-x64-20260823\bin\../share/yosys/lattice\common_sim.vh:159$1319'.
Removing empty process `$paramod$2074b3813575c9ede27f9a04ee0bf291c9c7bf2f\TRELLIS_DPR16X4.$proc$C:\FPGA-PROJECT\oss-cad-suite-windows-x64-20260823\bin\../share/yosys/lattice\common_sim.vh:159$1319'.
Removing empty process `$paramod$2074b3813575c9ede27f9a04ee0bf291c9c7bf2f\TRELLIS_DPR16X4.$proc$C:\FPGA-PROJECT\oss-cad-suite-windows-x64-20260823\bin\../share/yosys/lattice\common_sim.vh:151$1318'.
Cleaned up 1 empty switch.

6.46.4. Executing SCC pass (detecting logic loops).
Found 0 SCCs in module daq_system.
Found 0 SCCs.

6.46.5. Executing ABC9_OPS pass (helper functions for ABC9).

6.46.6. Executing TECHMAP pass (map to technology primitives).

6.46.6.1. Executing Verilog-2005 frontend: C:\FPGA-PROJECT\oss-cad-suite-windows-x64-20260823\bin\../share/yosys/techmap.v
Parsing Verilog input from `C:\FPGA-PROJECT\oss-cad-suite-windows-x64-20260823\bin\../share/yosys/techmap.v' to AST representation.
Generating RTLIL representation for module `\_90_simplemap_bool_ops'.
Generating RTLIL representation for module `\_90_simplemap_reduce_ops'.
Generating RTLIL representation for module `\_90_simplemap_logic_ops'.
Generating RTLIL representation for module `\_90_simplemap_compare_ops'.
Generating RTLIL representation for module `\_90_simplemap_various'.
Generating RTLIL representation for module `\_90_simplemap_registers'.
Generating RTLIL representation for module `\_90_shift_ops_shr_shl_sshl_sshr'.
Generating RTLIL representation for module `\_90_shift_shiftx'.
Generating RTLIL representation for module `\_90_fa'.
Generating RTLIL representation for module `\_90_lcu_brent_kung'.
Generating RTLIL representation for module `\_90_alu'.
Generating RTLIL representation for module `\_90_macc'.
Generating RTLIL representation for module `\_90_alumacc'.
Generating RTLIL representation for module `$__div_mod_u'.
Generating RTLIL representation for module `$__div_mod_trunc'.
Generating RTLIL representation for module `\_90_div'.
Generating RTLIL representation for module `\_90_mod'.
Generating RTLIL representation for module `$__div_mod_floor'.
Generating RTLIL representation for module `\_90_divfloor'.
Generating RTLIL representation for module `\_90_modfloor'.
Generating RTLIL representation for module `\_90_pow'.
Generating RTLIL representation for module `\_90_demux'.
Generating RTLIL representation for module `\_90_lut'.
Generating RTLIL representation for module `$connect'.
Generating RTLIL representation for module `$input_port'.
Successfully finished Verilog frontend.

6.46.6.2. Continuing TECHMAP pass.
No more expansions possible.
<suppressed ~168 debug messages>

6.46.7. Executing OPT pass (performing simple optimizations).

6.46.7.1. Executing OPT_EXPR pass (perform const folding).
Optimizing module $paramod$2074b3813575c9ede27f9a04ee0bf291c9c7bf2f\TRELLIS_DPR16X4.

6.46.7.2. Executing OPT_MERGE pass (detect identical cells).
Finding identical cells in module `$paramod$2074b3813575c9ede27f9a04ee0bf291c9c7bf2f\TRELLIS_DPR16X4'.
Computing hashes of 2 cells of `$paramod$2074b3813575c9ede27f9a04ee0bf291c9c7bf2f\TRELLIS_DPR16X4'.
Finding duplicate cells in `$paramod$2074b3813575c9ede27f9a04ee0bf291c9c7bf2f\TRELLIS_DPR16X4'.
Removed a total of 0 cells.

6.46.7.3. Executing OPT_MUXTREE pass (detect dead branches in mux trees).
Running muxtree optimizer on module $paramod$2074b3813575c9ede27f9a04ee0bf291c9c7bf2f\TRELLIS_DPR16X4..
  Creating internal representation of mux trees.
  No muxes found in this module.
Removed 0 multiplexer ports.

6.46.7.4. Executing OPT_REDUCE pass (consolidate $*mux and $reduce_* inputs).
  Optimizing cells in module $paramod$2074b3813575c9ede27f9a04ee0bf291c9c7bf2f\TRELLIS_DPR16X4.
Performed a total of 0 changes.

6.46.7.5. Executing OPT_MERGE pass (detect identical cells).
Finding identical cells in module `$paramod$2074b3813575c9ede27f9a04ee0bf291c9c7bf2f\TRELLIS_DPR16X4'.
Computing hashes of 2 cells of `$paramod$2074b3813575c9ede27f9a04ee0bf291c9c7bf2f\TRELLIS_DPR16X4'.
Finding duplicate cells in `$paramod$2074b3813575c9ede27f9a04ee0bf291c9c7bf2f\TRELLIS_DPR16X4'.
Removed a total of 0 cells.

6.46.7.6. Executing OPT_DFF pass (perform DFF optimizations).

6.46.7.7. Executing OPT_CLEAN pass (remove unused cells and wires).
Finding unused cells or wires in module $paramod$2074b3813575c9ede27f9a04ee0bf291c9c7bf2f\TRELLIS_DPR16X4..

6.46.7.8. Executing OPT_EXPR pass (perform const folding).
Optimizing module $paramod$2074b3813575c9ede27f9a04ee0bf291c9c7bf2f\TRELLIS_DPR16X4.

6.46.7.9. Finished fast OPT passes. (There is nothing left to do.)

6.46.8. Executing TECHMAP pass (map to technology primitives).

6.46.8.1. Executing Verilog-2005 frontend: C:\FPGA-PROJECT\oss-cad-suite-windows-x64-20260823\bin\../share/yosys/abc9_map.v
Parsing Verilog input from `C:\FPGA-PROJECT\oss-cad-suite-windows-x64-20260823\bin\../share/yosys/abc9_map.v' to AST representation.
Successfully finished Verilog frontend.

6.46.8.2. Continuing TECHMAP pass.
Using template $paramod$2074b3813575c9ede27f9a04ee0bf291c9c7bf2f\TRELLIS_DPR16X4 for cells of type $paramod$2074b3813575c9ede27f9a04ee0bf291c9c7bf2f\TRELLIS_DPR16X4.
No more expansions possible.
<suppressed ~5 debug messages>

6.46.9. Executing Verilog-2005 frontend: C:\FPGA-PROJECT\oss-cad-suite-windows-x64-20260823\bin\../share/yosys/abc9_model.v
Parsing Verilog input from `C:\FPGA-PROJECT\oss-cad-suite-windows-x64-20260823\bin\../share/yosys/abc9_model.v' to AST representation.
Generating RTLIL representation for module `$__ABC9_DELAY'.
Generating RTLIL representation for module `$__ABC9_SCC_BREAKER'.
Generating RTLIL representation for module `$__DFF_N__$abc9_flop'.
Generating RTLIL representation for module `$__DFF_P__$abc9_flop'.
Successfully finished Verilog frontend.

6.46.10. Executing ABC9_OPS pass (helper functions for ABC9).
<suppressed ~2 debug messages>

6.46.11. Executing ABC9_OPS pass (helper functions for ABC9).

6.46.12. Executing ABC9_OPS pass (helper functions for ABC9).
<suppressed ~2 debug messages>

6.46.13. Executing TECHMAP pass (map to technology primitives).

6.46.13.1. Executing Verilog-2005 frontend: C:\FPGA-PROJECT\oss-cad-suite-windows-x64-20260823\bin\../share/yosys/techmap.v
Parsing Verilog input from `C:\FPGA-PROJECT\oss-cad-suite-windows-x64-20260823\bin\../share/yosys/techmap.v' to AST representation.
Generating RTLIL representation for module `\_90_simplemap_bool_ops'.
Generating RTLIL representation for module `\_90_simplemap_reduce_ops'.
Generating RTLIL representation for module `\_90_simplemap_logic_ops'.
Generating RTLIL representation for module `\_90_simplemap_compare_ops'.
Generating RTLIL representation for module `\_90_simplemap_various'.
Generating RTLIL representation for module `\_90_simplemap_registers'.
Generating RTLIL representation for module `\_90_shift_ops_shr_shl_sshl_sshr'.
Generating RTLIL representation for module `\_90_shift_shiftx'.
Generating RTLIL representation for module `\_90_fa'.
Generating RTLIL representation for module `\_90_lcu_brent_kung'.
Generating RTLIL representation for module `\_90_alu'.
Generating RTLIL representation for module `\_90_macc'.
Generating RTLIL representation for module `\_90_alumacc'.
Generating RTLIL representation for module `$__div_mod_u'.
Generating RTLIL representation for module `$__div_mod_trunc'.
Generating RTLIL representation for module `\_90_div'.
Generating RTLIL representation for module `\_90_mod'.
Generating RTLIL representation for module `$__div_mod_floor'.
Generating RTLIL representation for module `\_90_divfloor'.
Generating RTLIL representation for module `\_90_modfloor'.
Generating RTLIL representation for module `\_90_pow'.
Generating RTLIL representation for module `\_90_demux'.
Generating RTLIL representation for module `\_90_lut'.
Generating RTLIL representation for module `$connect'.
Generating RTLIL representation for module `$input_port'.
Successfully finished Verilog frontend.

6.46.13.2. Continuing TECHMAP pass.
Using template $paramod$838872d5a4bab89607f53482b205c0fd50d8b82e\CCU2C for cells of type $paramod$838872d5a4bab89607f53482b205c0fd50d8b82e\CCU2C.
Using extmapper simplemap for cells of type $or.
Using extmapper simplemap for cells of type $and.
Using extmapper simplemap for cells of type $not.
Using extmapper simplemap for cells of type $xor.
Using template $paramod\LUT2\INIT=4'1010 for cells of type LUT2.
Using template $paramod\LUT4\INIT=16'1001011010101010 for cells of type LUT4.
Using extmapper simplemap for cells of type $mux.
No more expansions possible.
<suppressed ~207 debug messages>

6.46.14. Executing OPT pass (performing simple optimizations).

6.46.14.1. Executing OPT_EXPR pass (perform const folding).
Optimizing module daq_system.
<suppressed ~18 debug messages>

6.46.14.2. Executing OPT_MERGE pass (detect identical cells).
Finding identical cells in module `\daq_system'.
Computing hashes of 59 cells of `\daq_system'.
Finding duplicate cells in `\daq_system'.
Computing hashes of 57 cells of `\daq_system'.
Finding duplicate cells in `\daq_system'.
<suppressed ~6 debug messages>
Removed a total of 2 cells.

6.46.14.3. Executing OPT_MUXTREE pass (detect dead branches in mux trees).
Running muxtree optimizer on module \daq_system..
  Creating internal representation of mux trees.
  No muxes found in this module.
Removed 0 multiplexer ports.

6.46.14.4. Executing OPT_REDUCE pass (consolidate $*mux and $reduce_* inputs).
  Optimizing cells in module \daq_system.
Performed a total of 0 changes.

6.46.14.5. Executing OPT_MERGE pass (detect identical cells).
Finding identical cells in module `\daq_system'.
Computing hashes of 57 cells of `\daq_system'.
Finding duplicate cells in `\daq_system'.
Removed a total of 0 cells.

6.46.14.6. Executing OPT_DFF pass (perform DFF optimizations).

6.46.14.7. Executing OPT_CLEAN pass (remove unused cells and wires).
Finding unused cells or wires in module \daq_system..
Removed 0 unused cells and 55 unused wires.
<suppressed ~1 debug messages>

6.46.14.8. Executing OPT_EXPR pass (perform const folding).
Optimizing module daq_system.

6.46.14.9. Rerunning OPT passes. (Maybe there is more to do..)

6.46.14.10. Executing OPT_MUXTREE pass (detect dead branches in mux trees).
Running muxtree optimizer on module \daq_system..
  Creating internal representation of mux trees.
  No muxes found in this module.
Removed 0 multiplexer ports.

6.46.14.11. Executing OPT_REDUCE pass (consolidate $*mux and $reduce_* inputs).
  Optimizing cells in module \daq_system.
Performed a total of 0 changes.

6.46.14.12. Executing OPT_MERGE pass (detect identical cells).
Finding identical cells in module `\daq_system'.
Computing hashes of 57 cells of `\daq_system'.
Finding duplicate cells in `\daq_system'.
Removed a total of 0 cells.

6.46.14.13. Executing OPT_DFF pass (perform DFF optimizations).

6.46.14.14. Executing OPT_CLEAN pass (remove unused cells and wires).
Finding unused cells or wires in module \daq_system..

6.46.14.15. Executing OPT_EXPR pass (perform const folding).
Optimizing module daq_system.

6.46.14.16. Finished fast OPT passes. (There is nothing left to do.)

6.46.15. Executing AIGMAP pass (map logic to AIG).
Module daq_system: replaced 18 cells with 120 new cells, skipped 39 cells.
  replaced 3 cell types:
      14 $_MUX_
       2 $_OR_
       2 $_XOR_
  not replaced 3 cell types:
       4 $_AND_
       4 $_NOT_
      31 $specify2

6.46.16. Executing AIGMAP pass (map logic to AIG).
Module daq_system: replaced 59 cells with 353 new cells, skipped 96 cells.
  replaced 3 cell types:
      33 $_MUX_
      20 $_OR_
       6 $_XOR_
  not replaced 7 cell types:
      14 $_AND_
      20 $_NOT_
       4 $scopeinfo
      44 TRELLIS_FF
      10 $paramod$838872d5a4bab89607f53482b205c0fd50d8b82e\CCU2C
       2 $paramod$2074b3813575c9ede27f9a04ee0bf291c9c7bf2f\TRELLIS_DPR16X4
       2 $paramod$2074b3813575c9ede27f9a04ee0bf291c9c7bf2f\TRELLIS_DPR16X4_$abc9_byp

6.46.16.1. Executing ABC9_OPS pass (helper functions for ABC9).

6.46.16.2. Executing ABC9_OPS pass (helper functions for ABC9).

6.46.16.3. Executing XAIGER backend.
<suppressed ~11 debug messages>
Extracted 151 AND gates and 523 wires from module `daq_system' to a netlist network with 64 inputs and 69 outputs.

6.46.16.4. Executing ABC9_EXE pass (technology mapping using ABC9).

6.46.16.5. Executing ABC9.
Running ABC command: "<yosys-exe-dir>/yosys-abc" -s -f <abc-temp-dir>/abc.script 2>&1
ABC: ======== ABC command line "source <abc-temp-dir>/abc.script"
ABC: + read_lut <abc-temp-dir>/input.lut 
ABC: + read_box <abc-temp-dir>/input.box 
ABC: + &read <abc-temp-dir>/input.xaig 
ABC: + &ps 
ABC: <abc-temp-dir>/input : i/o =     64/     69  and =     126  lev =    8 (   0.99)  mem = 0.01 MB  box = 12  bb = 2
ABC: + &scorr 
ABC: Warning: The network is combinational.
ABC: + &sweep 
ABC: + &dc2 
ABC: + &dch -f -r 
ABC: + &ps 
ABC: <abc-temp-dir>/input : i/o =     64/     69  and =     118  lev =    7 (   0.79)  mem = 0.01 MB  ch =   11  box = 12  bb = 2
ABC: cst =       0  cls =     11  lit =      11  unused =     198  proof =     0
ABC: + &if -W 300 -v 
ABC: K = 7. Memory (bytes): Truth =    0. Cut =   76. Obj =  156. Set =  780. CutMin = no
ABC: Node =     118.  Ch =    11.  Total mem =    0.06 MB. Peak cut mem =    0.01 MB.
ABC: P:  Del = 1500.00.  Ar =      98.0.  Edge =      180.  Cut =      904.  T =     0.00 sec
ABC: P:  Del = 1500.00.  Ar =      94.0.  Edge =      169.  Cut =      904.  T =     0.00 sec
ABC: P:  Del = 1500.00.  Ar =      88.0.  Edge =      167.  Cut =     1435.  T =     0.00 sec
ABC: F:  Del = 1500.00.  Ar =      59.0.  Edge =      150.  Cut =      741.  T =     0.00 sec
ABC: A:  Del = 1500.00.  Ar =      57.0.  Edge =      140.  Cut =      733.  T =     0.00 sec
ABC: A:  Del = 1500.00.  Ar =      57.0.  Edge =      140.  Cut =      760.  T =     0.00 sec
ABC: Total time =     0.00 sec
ABC: + &write -n <abc-temp-dir>/output.aig 
ABC: + &mfs 
ABC: + &ps -l 
ABC: <abc-temp-dir>/input : i/o =     64/     69  and =     153  lev =    7 (   0.79)  mem = 0.01 MB  box = 11  bb = 2
ABC: Mapping (K=7)  :  lut =     39  edge =     139  lev =    3 (0.36)  levB =    5  mem = 0.00 MB
ABC: LUT = 39 : 2=9 23.1 %  3=9 23.1 %  4=15 38.5 %  5=3 7.7 %  6=2 5.1 %  7=1 2.6 %  Ave = 3.56
ABC: + &write -n <abc-temp-dir>/output.aig 
ABC: + &verify 
ABC: Networks are equivalent.  Time =     0.00 sec
ABC: + time 
ABC: elapse: 0.03 seconds, total: 0.03 seconds

6.46.16.6. Executing AIGER frontend.
<suppressed ~10 debug messages>
Removed 228 unused cells and 467 unused wires.

6.46.16.7. Executing ABC_OPS_REINTEGRATE pass (reintegrate ABC mapped design into module).
ABC RESULTS:              $lut cells:       42
ABC RESULTS:   $paramod$838872d5a4bab89607f53482b205c0fd50d8b82e\CCU2C cells:        9
ABC RESULTS:   $paramod$2074b3813575c9ede27f9a04ee0bf291c9c7bf2f\TRELLIS_DPR16X4_$abc9_byp cells:        2
ABC RESULTS:           input signals:       12
ABC RESULTS:          output signals:       27
<suppressed ~267 debug messages>
Removing temp directory.

6.46.17. Executing TECHMAP pass (map to technology primitives).

6.46.17.1. Executing Verilog-2005 frontend: C:\FPGA-PROJECT\oss-cad-suite-windows-x64-20260823\bin\../share/yosys/abc9_unmap.v
Parsing Verilog input from `C:\FPGA-PROJECT\oss-cad-suite-windows-x64-20260823\bin\../share/yosys/abc9_unmap.v' to AST representation.
Generating RTLIL representation for module `$__DFF_x__$abc9_flop'.
Generating RTLIL representation for module `$__ABC9_SCC_BREAKER'.
Successfully finished Verilog frontend.

6.46.17.2. Continuing TECHMAP pass.
Using template $paramod$2074b3813575c9ede27f9a04ee0bf291c9c7bf2f\TRELLIS_DPR16X4 for cells of type $paramod$2074b3813575c9ede27f9a04ee0bf291c9c7bf2f\TRELLIS_DPR16X4.
Using template $paramod$838872d5a4bab89607f53482b205c0fd50d8b82e\CCU2C for cells of type $paramod$838872d5a4bab89607f53482b205c0fd50d8b82e\CCU2C.
Using template $paramod$2074b3813575c9ede27f9a04ee0bf291c9c7bf2f\TRELLIS_DPR16X4_$abc9_byp for cells of type $paramod$2074b3813575c9ede27f9a04ee0bf291c9c7bf2f\TRELLIS_DPR16X4_$abc9_byp.
No more expansions possible.
<suppressed ~21 debug messages>
Removed 15 unused cells and 717 unused wires.

6.47. Executing TECHMAP pass (map to technology primitives).
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

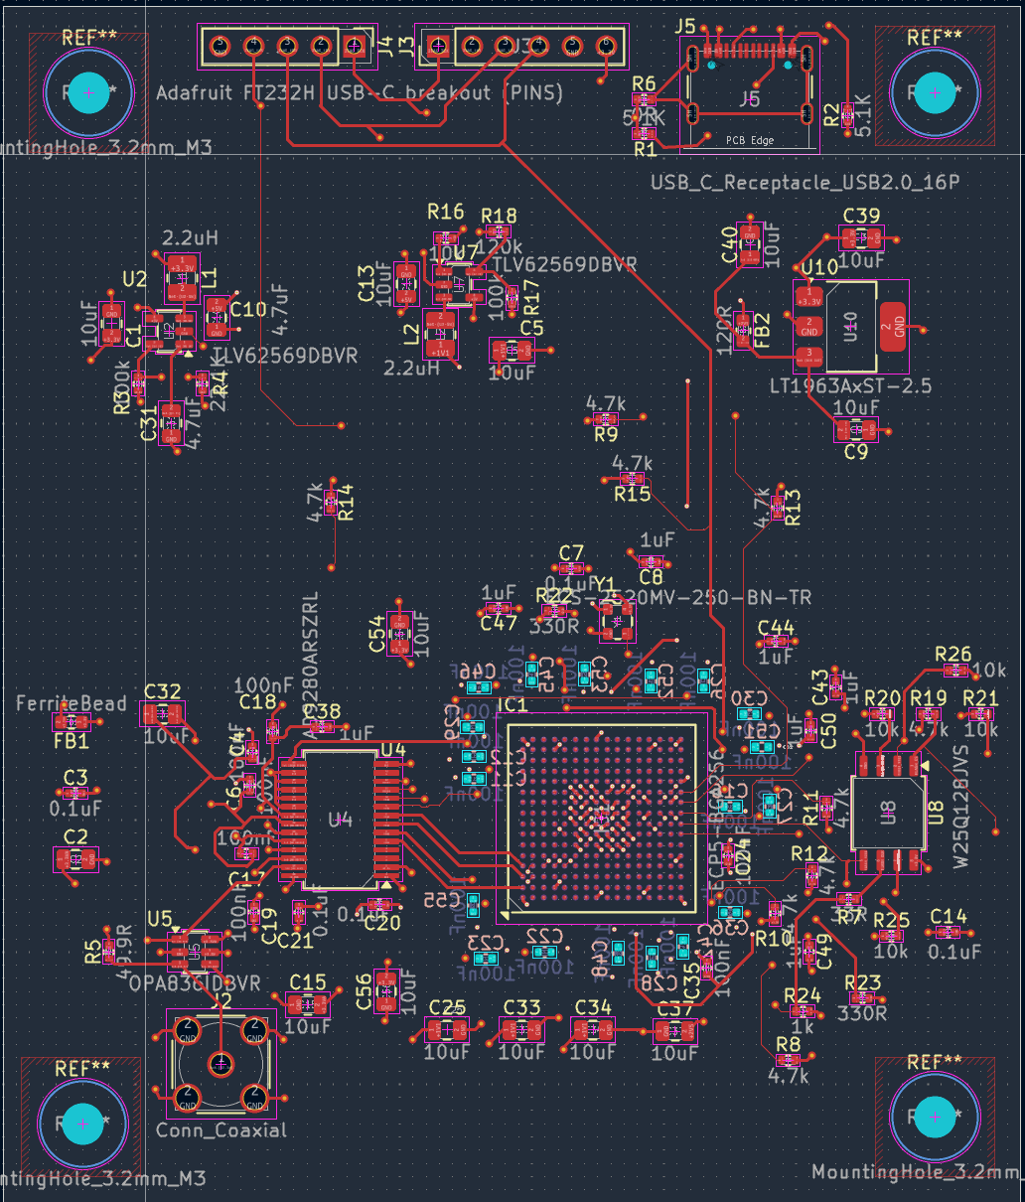
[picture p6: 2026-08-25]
hardware/kicad/PCB/front__board_connections.png

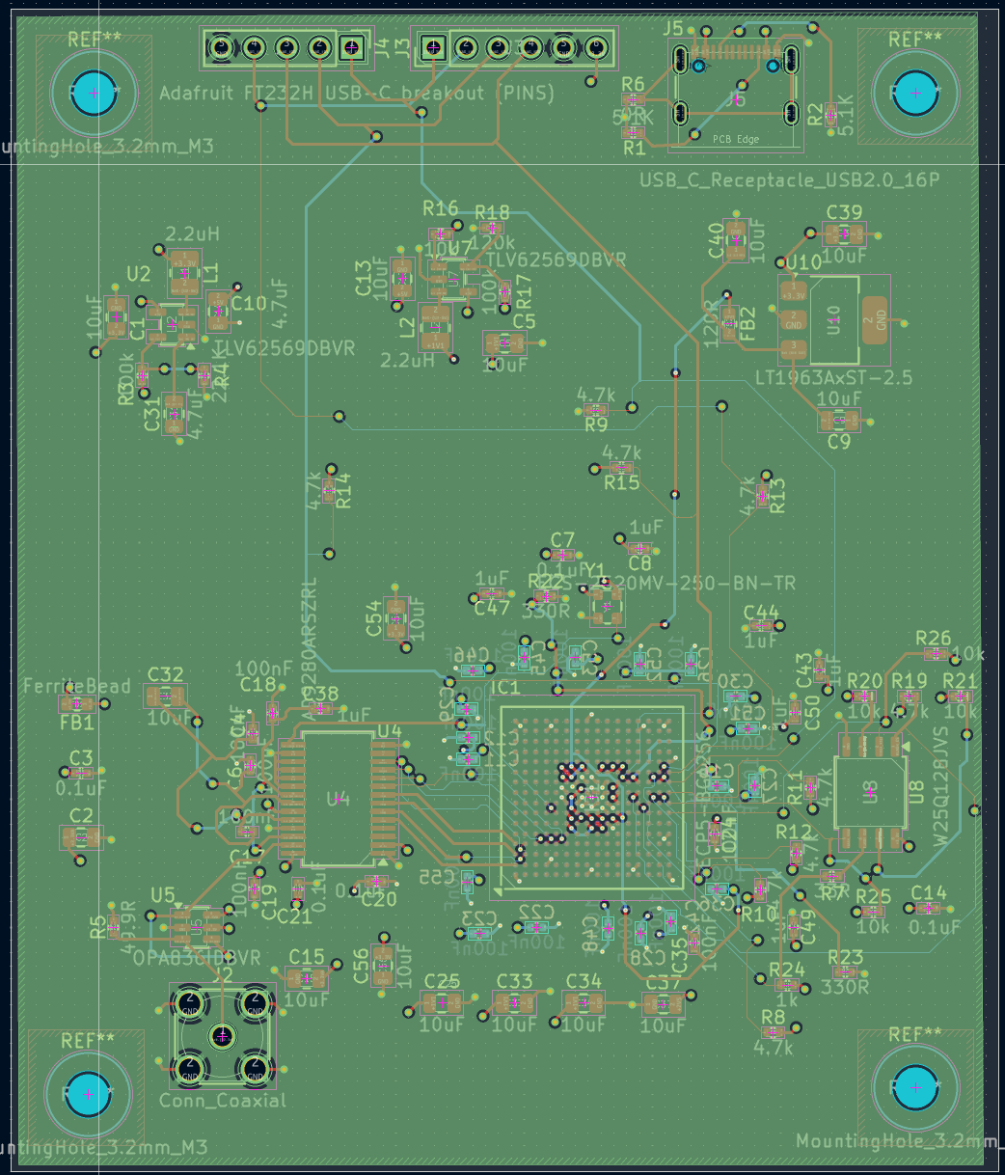
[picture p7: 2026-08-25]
hardware/kicad/PCB/GND_ZONE.png

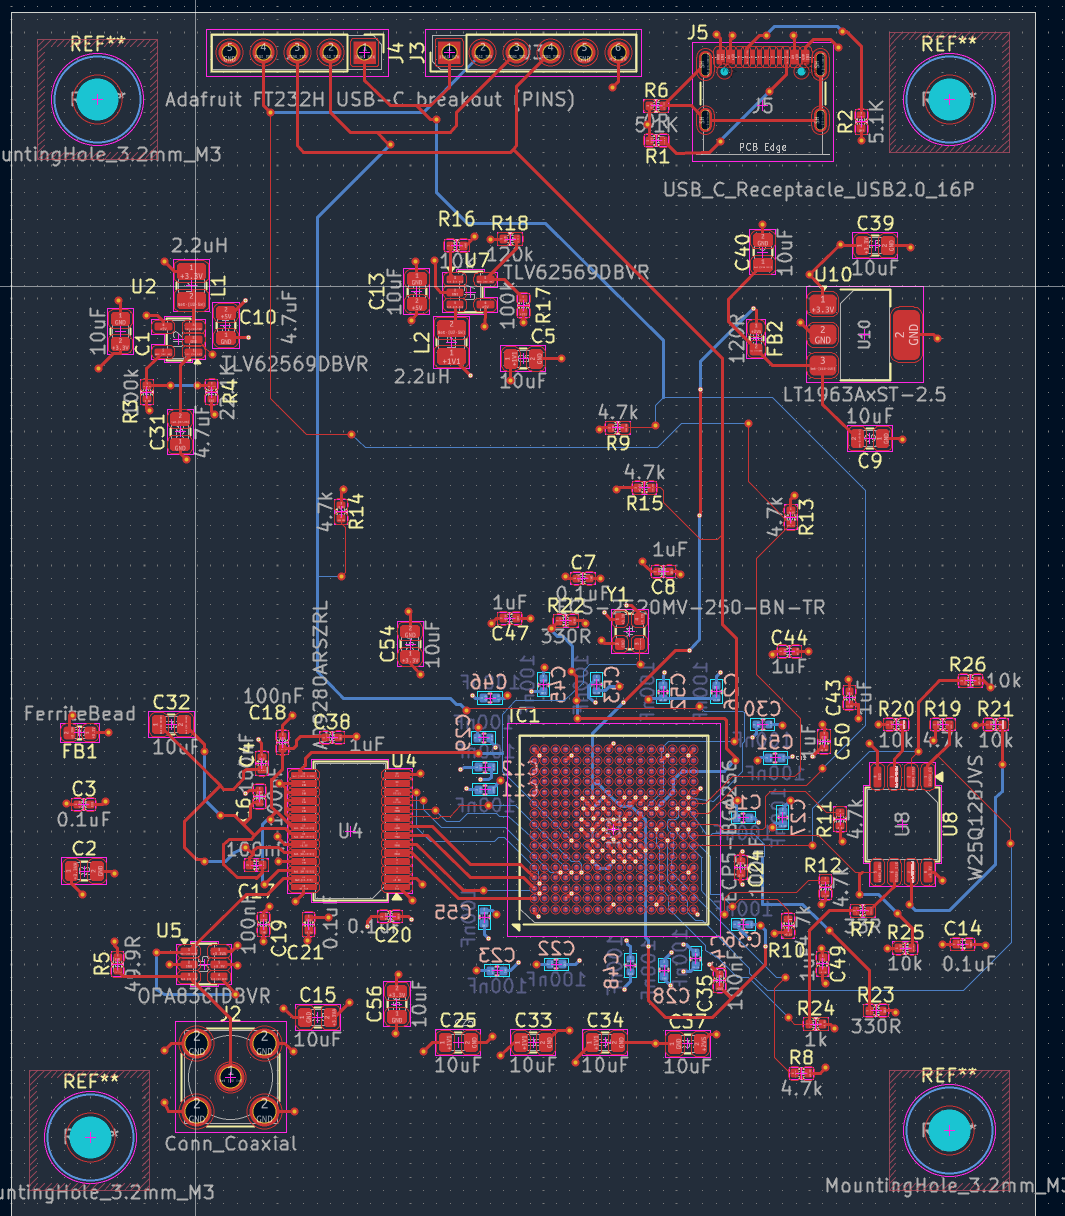
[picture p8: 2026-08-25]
hardware/kicad/PCB/PCB_.png

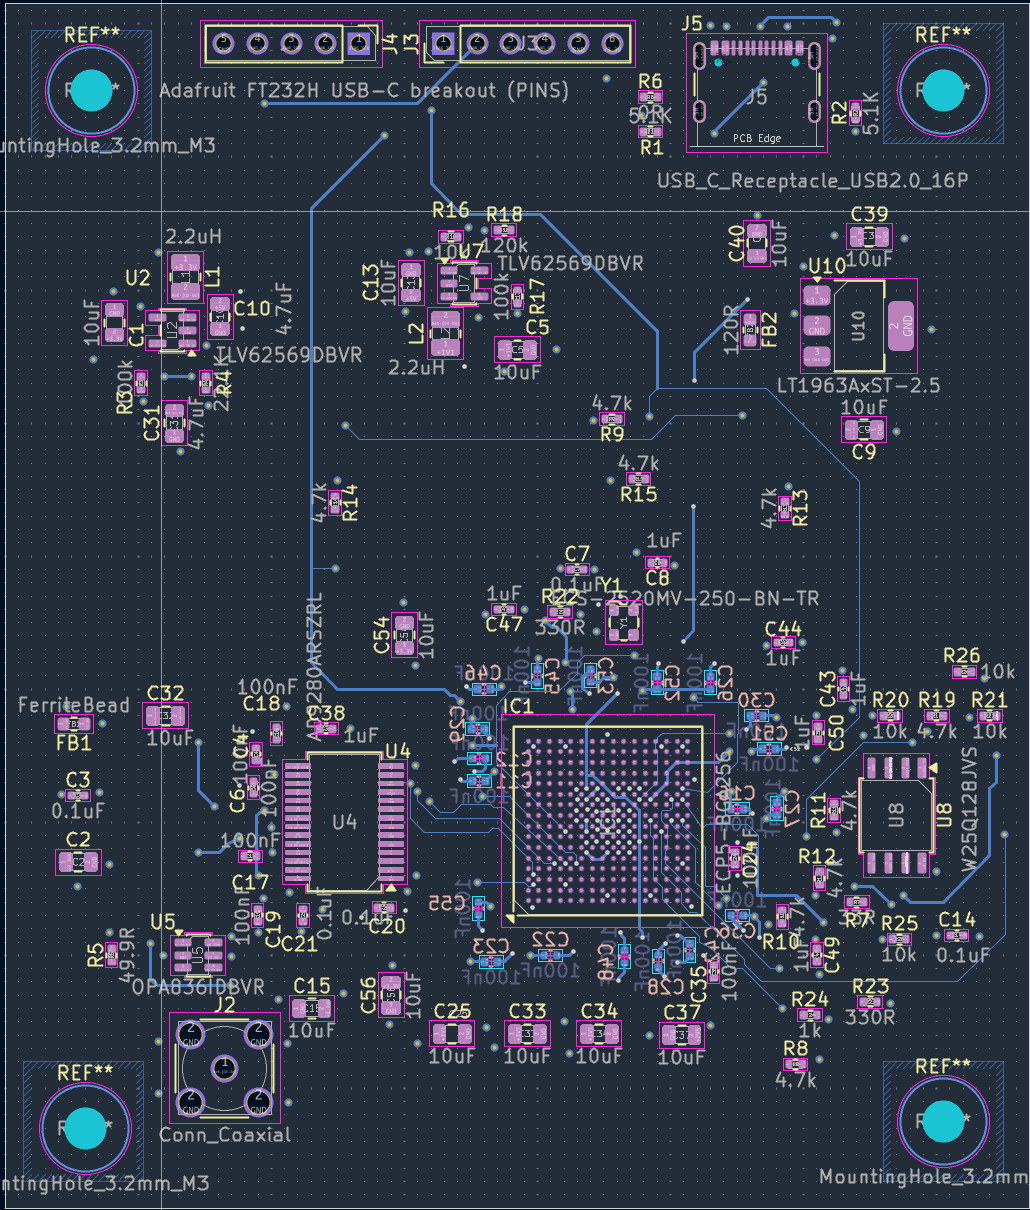
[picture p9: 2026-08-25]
hardware/kicad/PCB/Back_board_connections.png

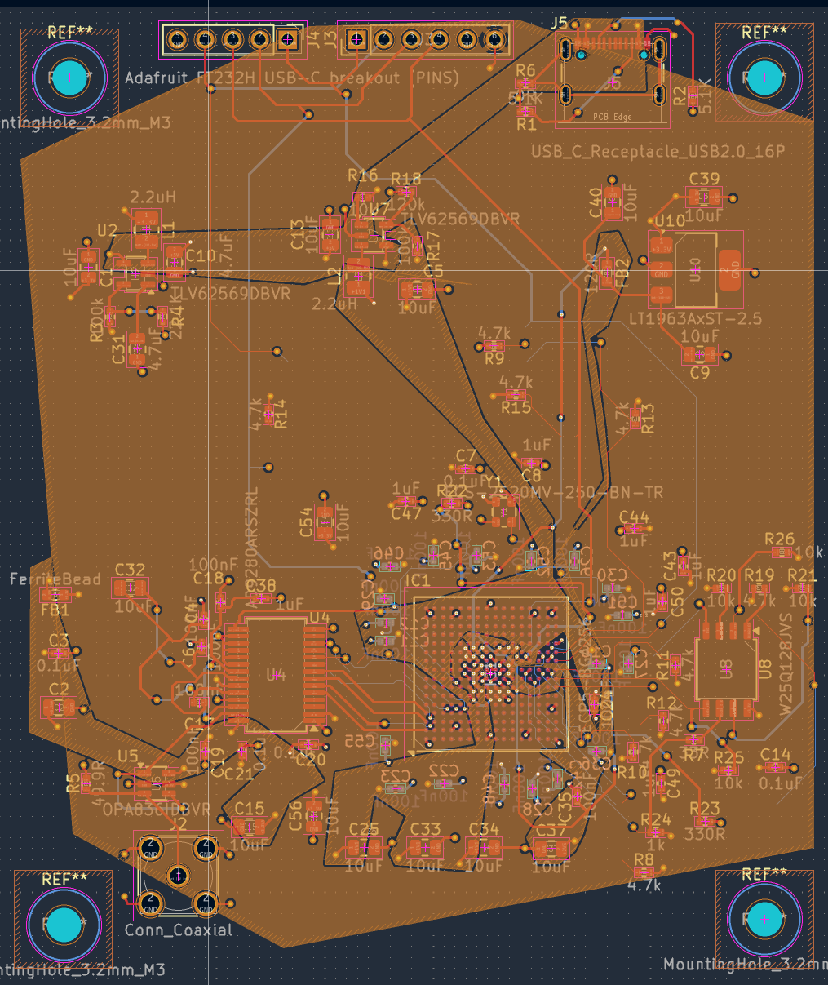
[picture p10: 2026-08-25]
hardware/kicad/PCB/power_filled_zones.png

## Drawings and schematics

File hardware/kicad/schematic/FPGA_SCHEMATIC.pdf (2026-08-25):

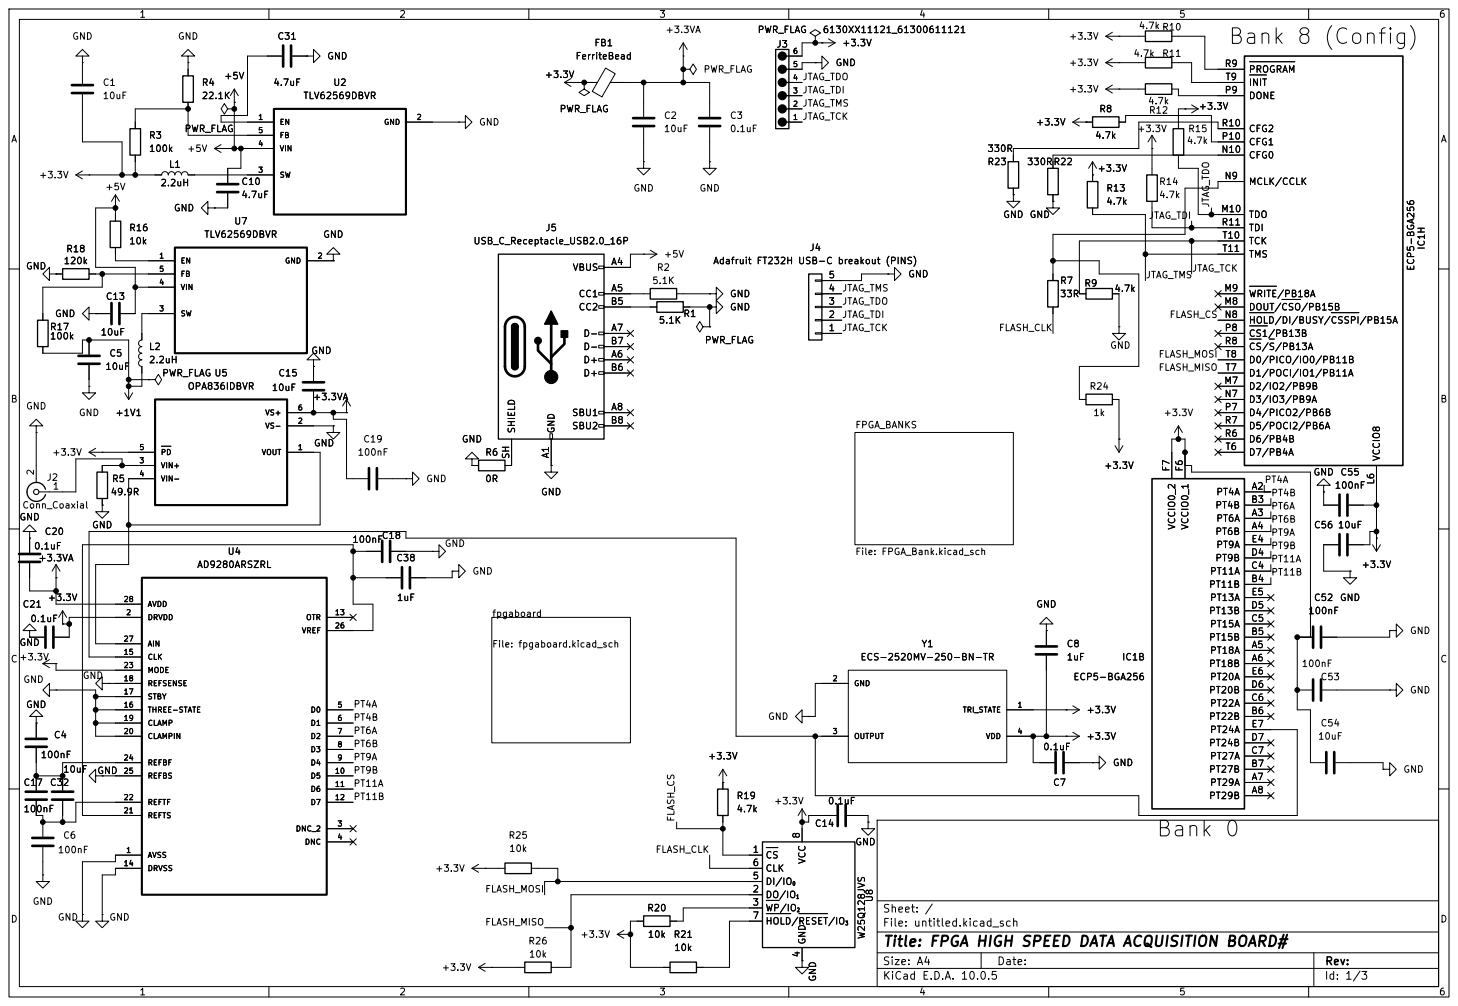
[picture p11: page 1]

Adafruit FT232H USB-C breakout (PINS) 1

4 DI/IO0 5 CLK 6 HOLD/RESET/IO3 7 VCC

Sheet: /
File: untitled.kicad_sch
Title: FPGA HIGH SPEED DATA ACQUISITION BOARD#

Size: A4 | Rev:
KiCad E.D.A. 10.0.5 | Id: 1/3

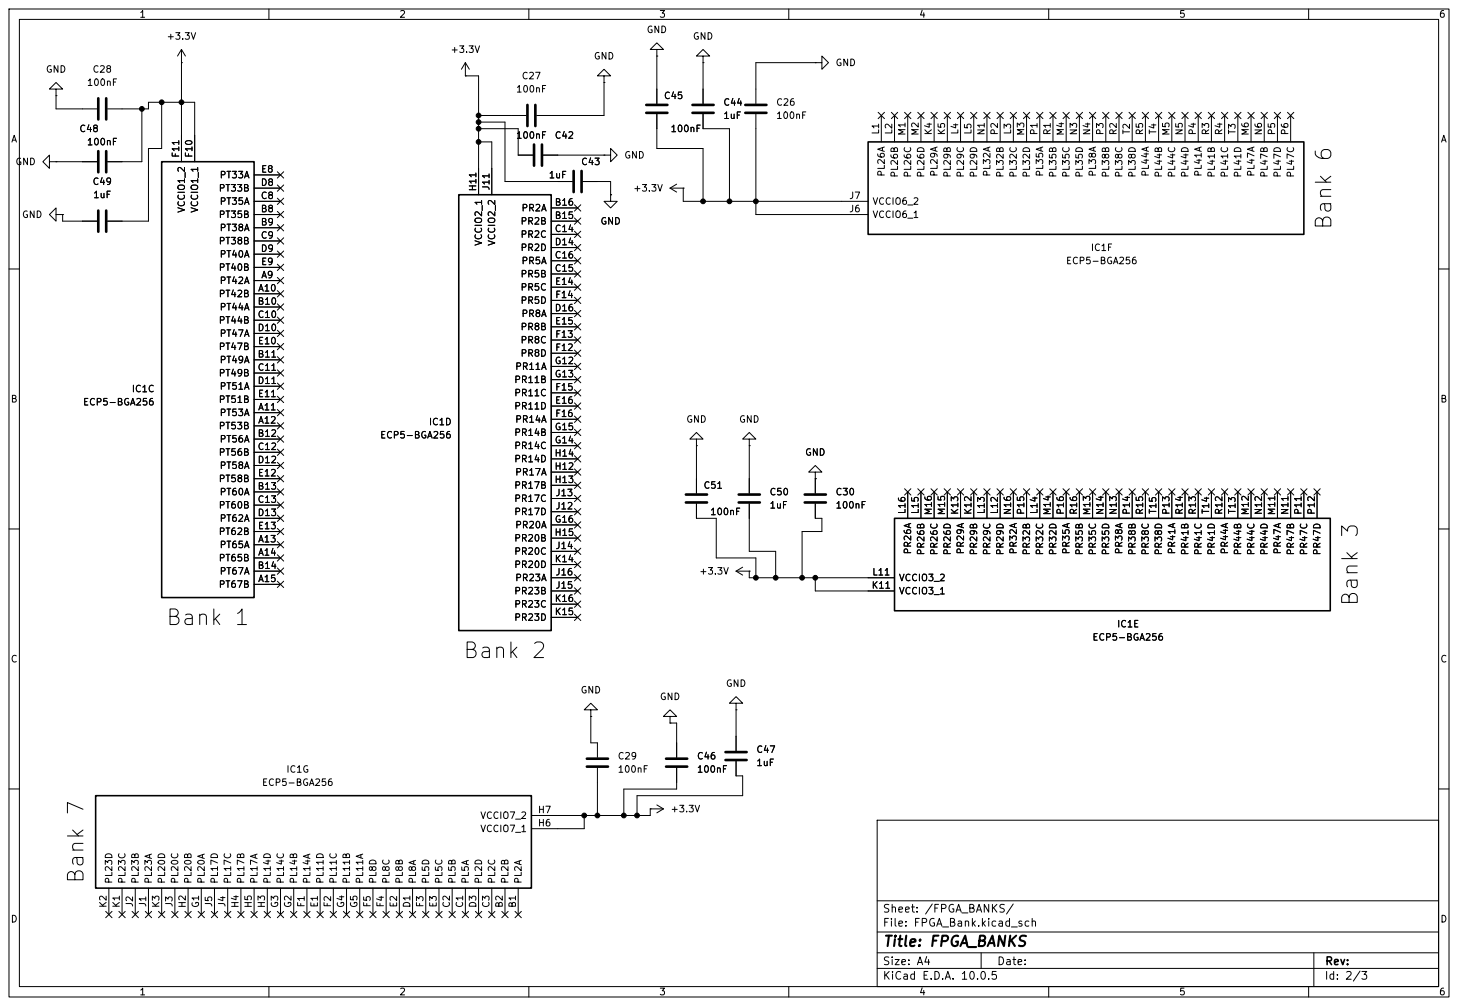
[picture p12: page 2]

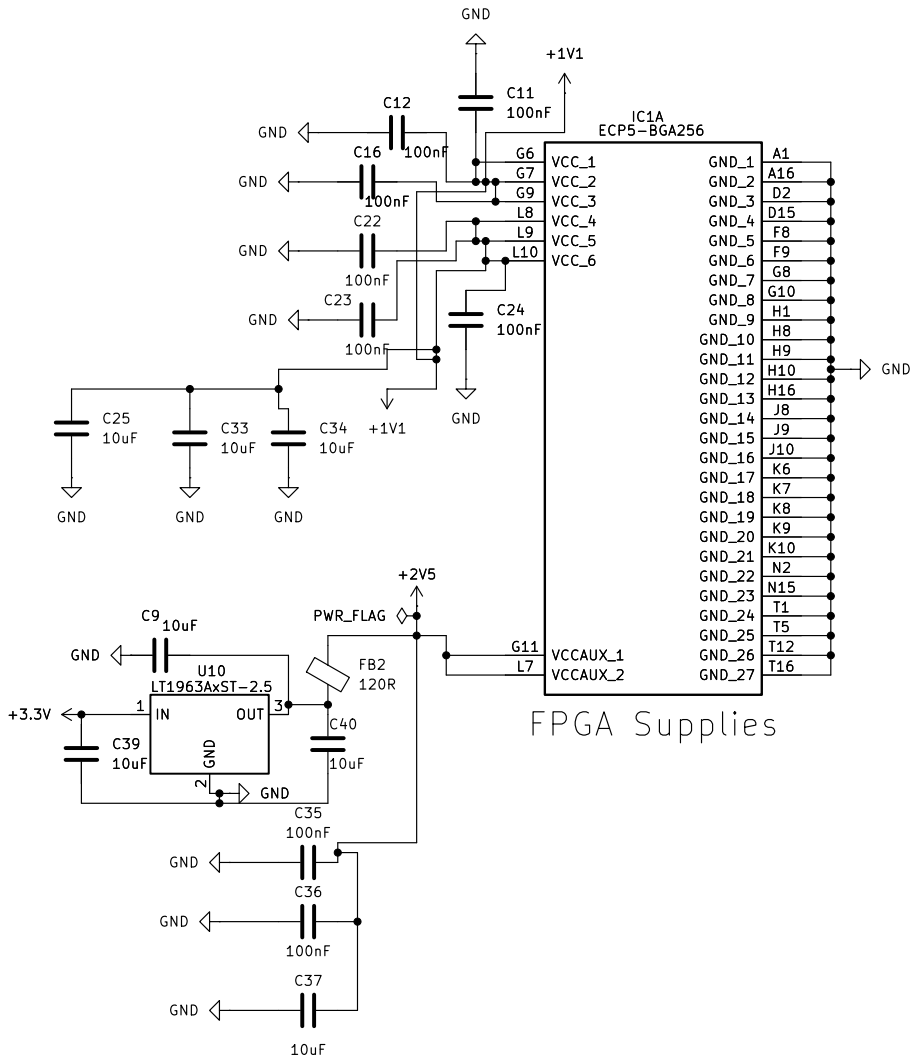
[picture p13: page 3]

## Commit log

2026-08-25 Create kicad_pic
2026-08-25 PCB 3D RENDER
2026-08-25 Add hardware design documentation for FPGA board
    Added detailed documentation about the hardware design, components, PCB stack-up, power architecture, ADC to FPGA interface, clocking, FPGA configuration, layout considerations, PCB renders, and desi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
2026-08-25 Bill of materials
    [FPGA_BOM.csv]
2026-08-25 fabrication files
    [FPGA PROJECT-B_Cu.gbr, FPGA PROJECT-B_Mask.gbr, FPGA PROJECT-B_Paste.gbr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]
2026-08-25 PCB images
2026-08-25 Update README with PCB design rationale
    Clarified reasons for using a 4-layer PCB design and benefits of the dedicated ground and power layers.
